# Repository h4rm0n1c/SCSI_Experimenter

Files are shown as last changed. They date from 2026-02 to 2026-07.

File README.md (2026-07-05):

# SCSI Experimenter

A 33C93A/WD33C93-based SCSI experimenter board for microcontroller projects, with a complete software architecture for running it from a Raspberry Pi Pico W or Pico 2 W.

## What it is

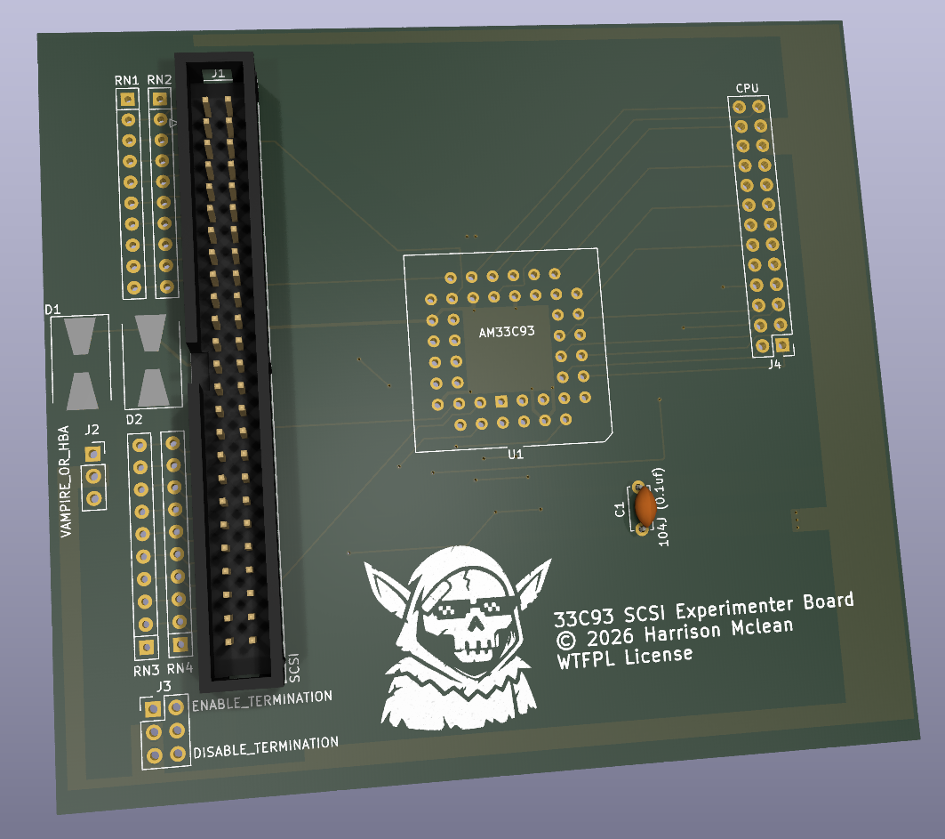
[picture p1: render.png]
SCSI Experimenter board render


This repo contains:

- **KiCad hardware design** — a breakout board built around the AM33C93A/WD33C93A SCSI bus interface controller, with a 26-pin CPU header and 50-pin SCSI-1 connector, passive 220/330Ω termination, and TERMPWR direction switch (HBA/vampire modes).
- **Complete software architecture** — verified PIO firmware design for initiator and target modes, documented at `ARCHITECTURE.md` (1184 lines).
- **Verification tools** — cycle-accurate PIO timing simulation, real `pioasm` compilation checks, and KiCad netlist extraction.
- **Datasheets** — AM33C93A, WD33C93A/B, RP2040, RP2350, and SCSI-1 spec, plus extracted text layers.

## Repository structure

```
├── ARCHITECTURE.md          — Complete software architecture reference
├── scsi/                    — KiCad PCB design files
│   ├── scsi.kicad_sch       — Schematic (S-expression)
│   ├── scsi.kicad_pcb       — PCB layout
│   └── scsi.kicad_pro       — Project metadata
├── h4rm0n1c.kicad_sym       — AM33C93A/AM33C93A KiCad symbol
├── render.png               — Board render
├── docs/                    — Datasheets and references
│   ├── AM33C93A.pdf         — AMD datasheet (49 pages)
│   ├── WD33C93A.pdf         — WD variant datasheet
│   ├── WD33C93B.pdf         — Enhanced version datasheet
│   ├── WD33C93A-appnotes.pdf — Combined datasheet + app notes + errata
│   ├── SCSI-1-spec.pdf      — ANSI X3.131-1986
│   ├── RP2040-datasheet.pdf — RP2040 microcontroller
│   ├── RP2350-datasheet.pdf — RP2350 microcontroller
│   ├── PicoW-pinout-diagram.pdf
│   ├── Pico2W-pinout-diagram.pdf
│   └── PICO_GPIO_CHEATSHEET.md — Verified GPIO reference
├── docs-extracted/          — pdftotext of searchable datasheets
│   ├── WD33C93A-appnotes.txt
│   └── WD33C93B.txt
└── tools/                   — Verification tools
    ├── check_pio_timing.py  — Stage 1: timing simulator
    ├── assemble_pio.py      — Stage 2: pioasm compilation + cross-check
    ├── extract_netlist.py   — KiCad PCB netlist dumper
    └── README.md            — Tool documentation
```

## Quick start

### 1. Hardware

The board has a 26-pin CPU header (J4) that connects directly to a Pico 2 W GPIOs — no level shifters required (RP2350 GPIOs are 5V tolerant). For RP2040/Pico W builds, a 74LVC8T245 is needed on the data bus.

See `ARCHITECTURE.md` §0 (§0 for the J4 pinout and §1 for the GPIO map.

### 2. Validation

From the repo root, verify the PIO design:

```bash
python3 tools/check_pio_timing.py   # timing simulation against datasheet specs
python3 tools/assemble_pio.py       # real pioasm compilation
```

Both should exit 0.

### 3. Reading the architecture

Start with `ARCHITECTURE.md`:

- **§0–1** — Board discovery and GPIO allocation
- **§2** — PIO state machine design (register engine + burst DMA)
- **§3** — Register access layer and C API
- **§4** — SCSI bus phase engine (initiator)
- **§5** — Interrupt vs polling vs DMA analysis
- **§6** — Clock generation
- **§7** — RP2040 vs RP2350 comparison
- **Appendices F–I** — Complete register reference, interrupt codes, command reference, target mode

## Architecture highlights

- **PIO-based bus interface** — two state machines in one PIO block (22 of 32 instruction slots), driving all 33C93A register accesses with hardware-bounded strobes. No CPU bit-banging.
- **Burst DMA** — DRQ/DACK-paced PIO engine + DMA channel for data phases, zero CPU per byte, ~2.5 MB/s throughput.
- **SM clock 24 MHz** — derived from 120 MHz sysclk, chosen so all timing minima land on integer cycle counts with margin.
- **Indirect addressing** — ALE is grounded on this board, so every register access is a two-cycle operation.
- **Dual board support** — same firmware binary runs on Pico W and Pico 2 W (Pico 2 W recommended for zero-glue wiring).

## Variant support

The architecture covers the full WD33C93 family — original WD33C93, WD33C93A, WD33C93B, and AMD AM33C93A. All variant-specific features are flagged `[A+]` or `[B]` throughout the reference. The fitted chip on this board is the WD33C93B, which is used as the primary reference.

## Target mode

The 33C93A supports both initiator and target SCSI roles. The architecture covers target mode in Appendix I, including Wait-for-Select-and-Receive (0Ch) as the recommended parked state, reselection handling, and the full set of target commands. The PIO layer is identical regardless of mode.

## License

WTFPL — see the schematic title block.

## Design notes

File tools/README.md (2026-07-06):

# Tools

Work products from the ARCHITECTURE.md design session (2026-07-05).
These regenerate/verify the evidence the architecture document is
built on. Run everything from the repo root.

## check_pio_timing.py — PIO program validator & timing simulator

```
python3 tools/check_pio_timing.py
```

Parses the `pioasm` code blocks **directly out of ARCHITECTURE.md** and:

1. **Encoding check** — enforces the `.side_set 3` (non-optional) field
   budget: side annotation on every instruction, side values ≤ 3 bits,
   delays ≤ `[3]`. This catches the class of bug found in review (the
   original draft used `.side_set 3 opt`, which only leaves 1 delay bit,
   with `[4]`/`[2]` delays that would not assemble).
2. **Cycle-accurate timing simulation** — replays each program at the
   24 MHz SM clock (120 MHz sys ÷ 5), measures every strobe's low width,
   inter-strobe recovery, and `in pins` sample age (including the
   2-sys_clk input-synchronizer latency, −16.7 ns), and asserts them
   against the WD33C93A app-notes limits (§9.1.3/9.1.4 indirect register
   access, §9.1.11/9.1.12 burst DMA).

Exit code 0 = all pass. **Re-run this after any edit to the PIO
listings, the SM divider, or the sys_clk choice in ARCHITECTURE.md** —
the spec table in the script is the single place the datasheet numbers
live.

## assemble_pio.py — stage-2: real pioasm compilation

```
python3 tools/assemble_pio.py
```

Runs **after** `check_pio_timing.py` as the second stage of a two-stage
validation. Stage 1 checks field budgets and simulates timing but only
*parses* the source; stage 2 feeds the exact same code blocks to the
real `pioasm` (prebuilt at
`/home/harri/pico/EBD_IPKVM/build/pioasm-install/pioasm/pioasm`, falls
back to `$PATH`, then to building from
`/home/harri/pico/pico-sdk/tools/pioasm`) and verifies its output:

- each `.program` compiles standalone (syntax, jump targets, delay
  limits — pioasm itself rejects the `.side_set 3 opt` + `[2+]` class
  of bug found in review, so this stage catches it mechanically);
- generated `sm_config_set_sideset(&c, 3, false, false)` matches the
  required 3-bit / mandatory / pins config for every program;
- instruction-array length, wrap(target,top), and the 32-slot budget;
- the `mov osr, ~null` idiom decodes to 0xA0EB
  (MOV | dest OSR | invert | src NULL), checked standalone and per
  occurrence in-program under the side/delay field mask;
- **cross-check against stage 1**: per-program instruction counts from
  `check_pio_timing.py`'s parser must match pioasm's — catches any
  extraction/regex divergence between the two tools;
- **pio_version must be 0** (RP2040/RP2350 compatible); a non-zero
  version means an RP2350-only instruction crept in and breaks the
  ARCHITECTURE.md both-boards guarantee → FAIL.

Exit 0 = all compiled and matched. Never modifies ARCHITECTURE.md —
it validates whatever the doc actually says.

## pio_sim.py — stage-3: behavioral simulation vs a mock 33C93A

```
python3 tools/pio_sim.py [-v]
```

Stage 1 proves the strobe timing, stage 2 proves the source assembles —
neither proves the programs implement the **protocol**. Stage 3
executes the programs cycle-by-cycle against a mock WD33C93A register
file and checks what the chip would actually *do*:

- **Executes real machine words.** A built-in assembler turns the
  ARCHITECTURE.md `pioasm` blocks into 16-bit PIO instructions, then a
  cycle-accurate SM model (OSR/ISR shifts, autopush/autopull, FIFO
  stalls, side-set-on-first-cycle, delay cycles, pindirs, the 2-sys_clk
  input-synchronizer age) decodes and runs the *words* — so a
  mis-encoded field is an execution failure. The assembled `sbic_bus`
  is cross-checked word-for-word against the pioasm 2.2.0 output
  captured in `../session/6e23006d-*` (golden reference embedded).
- **Mock chip enforces the datasheet at every pin edge**: indirect
  Address-register protocol with its auto-increment exceptions
  (Aux Status / Data 19h / Command 18h — app notes §6.2.2, B datasheet
  §3.1.2), strobe min/max widths and recovery (§9.1.3/9.1.4), read
  data driven only after tRLDV — a program that samples early gets
  garbage *and* a logged violation — data setup on writes, bus
  contention, DACK̅-vs-CS̅ exclusion (E024), MR̅ ≥ 1 µs, INTRQ
  set/clear semantics (§9.1.13), the 7 µs LCI rule, and DRQ̅/DACK̅
  burst handshaking.
- **Chip-variant-aware burst timing** (`chip_variant="A"|"B"` on
  `Bus`/`Sim`/`MockWD33C93A`, default A = worst case). A enforces
  §9.1.11/9.1.12: every read byte independently valid ≤ 50 ns from
  RE̅↓, strobes ≥ 80/50 ns, setup ≥ 25 ns, recovery ≥ 80 ns. B
  enforces §6.1.11/6.1.12: strobes ≥ 30 ns, setup ≥ 18 ns, and the
  *pipelined* read model — the mock only makes the first byte valid
  ≤ 50 ns from DACK̅↓ (tDLDV) and each later byte ≤ 80 ns from the
  *previous* RE̅↑ (tRHDV), so an SM that strobes faster than the
  pipeline delivers reads garbage and fails functionally.

Tests (any datasheet violation fails the test that produced it):

| Test | Proves |
|---|---|
| `golden-encoding` | assembler == session pioasm 2.2.0 words |
| `init-sequence` | **SM0 full init: MR̅ pulse → wait INTRQ → read SCSI Status (INTRQ clears) → write Own ID → read it back** |
| `aux-status` | A0=0 read returns Aux Status, Address reg untouched |
| `auto-increment` | CDB 03h–06h in 1+N cycles; Data 19h doesn't advance |
| `lci-7us-rule` | command <7 µs after status read ignored + LCI; ≥7 µs accepted (soft reset → interrupt 00h) |
| `burst-in` / `burst-out` | SM1 DRQ̅/DACK̅ bursts (A variant) move every byte in order, CS̅ high, completion INTRQ, DRQ̅ deasserts |
| `golden-burst-pipeline` | B variant: 12 bytes arrive intact under the pipelined validity model, and every prev-RE̅↑ → next-RE̅↓ gap ≥ 80 ns (the §2 claim that B data is stable before its strobe even falls) |
| `variant-probe` | Appendix E item 9 works: soft reset with EAF+RAF → SCSI Status 01h on both variants; CDB1 = microcode revision on a B, 0 on an A |
| `fifo-stall-hazard` | the §2 warning is real: a 5th un-drained SM0 read wedges `in pins` with RE̅ low, and the mock flags the tRE ≤ 10 µs violation |

The mock's checks are mutation-tested: shortening a strobe delay or
moving the read sample earlier makes the corresponding test fail.
Timing constants deliberately mirror `check_pio_timing.py`. Exit 0 =
all tests pass. Like the other stages it never modifies
ARCHITECTURE.md — it validates whatever the doc actually says.

**Validation flow after any PIO-related edit:**
```
python3 tools/check_pio_timing.py   # encoding budget + timing sim
python3 tools/assemble_pio.py       # real compiler + config verification
python3 tools/pio_sim.py            # behavioral sim vs mock 33C93A
```

## extract_netlist.py — KiCad PCB netlist dump

```
python3 tools/extract_netlist.py [repo/scsi/scsi.kicad_pcb]
```

Dumps pad → net for every footprint. The schematic has no net labels,
so this is how the J4 "CPU" header pinout, the grounded-ALE discovery,
the direct-to-header SCSI RST routing, and the J2/J3 termination/TERMPWR
analysis in ARCHITECTURE.md §0 were derived. U1 pads are annotated with
AM33C93A pin names (from `repo/h4rm0n1c.kicad_sym`, verified against the
AMD datasheet PLCC-44 connection diagram).

# ../docs-extracted/

`pdftotext` extractions of the datasheets that have text layers, kept
because the searchable text is what all register/timing citations in
ARCHITECTURE.md came from.

**OCR reliability status (verified 2026-07-05):** prose and register
bit descriptions extract fine, but **multi-column timing tables come
out with jumbled columns — do not trust extracted timing numbers.**
Every timing value used by ARCHITECTURE.md / check_pio_timing.py was
re-verified by reading the PDF pages as images: A app notes pp. 52–53
(indirect R/W), 60–62 (burst DMA, INTRQ); B datasheet pp. 47–49 (CLK,
MR̅, indirect R/W), 56–57 (burst DMA). The complete SCSI Status
interrupt-code tables and MCI decode (Appendix G) were likewise
verified against B datasheet pp. 21–24 — every code value, state
column, and meaning matched (one wording nuance fixed at 14h). One extraction-induced error was
found and fixed (A burst-read tRLDV is 50 ns, not 70), plus one real
finding (B burst reads are pipelined from DACK̅↓/previous RE̅↑). If you
pull new timing numbers from these .txt files, verify the page visually
first:

- `WD33C93A-appnotes.txt` — register map, indirect-addressing rules, all
  host-bus timing tables, errata index (E018/E022/E024/E040/E049…).
- `WD33C93B.txt` — command opcode table, B-variant differences.
- `SCSI-1-spec.txt` (ANSI X3.131-1986) — **kept local-only, not
  committed**: it is the full text of a paid ANSI standard. Regenerate
  with `pdftotext SCSI-1-spec.pdf docs-extracted/SCSI-1-spec.txt` from a
  locally obtained copy of the standard.

Not present: `AM33C93A.pdf` and `WD33C93A.pdf` are page scans with no
text layer (extraction yields nothing) — consult those PDFs visually;
the AMD PLCC-44 connection diagram is on datasheet page 1-5.

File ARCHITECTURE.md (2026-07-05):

# Pico ↔ AM33C93A SCSI Board — Software Architecture

Target: Raspberry Pi Pico W (RP2040) or Pico 2 W (RP2350) as the host
processor for the h4rm0n1c AM33C93A/WD33C93A experimenter board, SCSI-1
narrow initiator mode.

Sources: `repo/scsi/scsi.kicad_sch` + `scsi.kicad_pcb` (netlist verified
pad-by-pad), `repo/h4rm0n1c.kicad_sym`, AMD Am33C93A datasheet (Nov 1991,
pub #11853), WD33C93A datasheet + app notes (Nov 1990, incl. errata
E018/E022/E024/E049), WD33C93B datasheet, ANSI X3.131-1986,
`docs/PICO_GPIO_CHEATSHEET.md`, RP2040/RP2350 datasheets.

---

## 0. What the board actually is (netlist findings)

Extracted from `scsi.kicad_pcb` (authoritative — the schematic has no net
labels, everything is point-to-point wiring):

* **U1** — AM33C93A, PLCC-44. Pinout in the KiCad symbol matches the AMD
  datasheet connection diagram exactly.
* **J1** — 50-pin SCSI-1 connector. All odd pins + 20–24/28–30/34 GND,
  pin 25 open, pin 26 TERMPWR. SD0–SD7/SDP and the nine control lines go
  straight from U1's SCSI-side pins to J1 (open-drain 48 mA drivers on
  chip, no external transceivers — single-ended SCSI, as expected).
* **J4 "CPU"** — 26-pin (2×13) host header. **This is the Pico's world.**
  Full pinout below.
* **J3 "ENABLE_TERMINATION"** — connects the commons of RN1/RN3 (330 Ω)
  to GND and RN2/RN4 (220 Ω) to +5 V: classic SCSI-1 passive 220/330
  termination on all 18 signals, jumper-enabled.
* **J2 "VAMPIRE_OR_HBA"** — TERMPWR direction select through two SS33
  Schottkys: *HBA* position sources J1-26 TERMPWR from the board's +5 V
  (D1); *VAMPIRE* position back-feeds the board's +5 V rail *from* bus
  TERMPWR (D2).
* **ALE (U1 pin 27) is hard-wired to GND.** This is deliberate: per the
  WD33C93A datasheet §6.2.2, grounding ALE selects **indirect
  addressing** — there is no address bus, only A0. Every register access
  is a two-cycle operation (see §3).
* **SCSI RST (J1 pin 40) does not touch U1 at all** — the 33C93 family
  has **no RST pin**. The board routes RST straight to **J4 pin 7** so
  the host processor asserts and monitors bus reset itself.
* **DP (U1 pin 11 → J4 pin 3)** — host-bus data parity. On the PLCC part
  parity is *always generated* on DP during reads; *checking* of host
  parity is optional (Own ID bit EHP). Safe to leave unused.
* Test pins **1 (SI), 22 (SCLK), 36 (HALT)** are unconnected — correct
  per the AMD datasheet note ("test purposes only").

### J4 host header pinout (verified against PCB netlist)

| J4 pin | Signal | U1 pin | Dir (Pico view) | J4 pin | Signal | U1 pin | Dir |
|---|---|---|---|---|---|---|---|
| 1 | DRQ̅ | 9 | in | 2 | DACK̅ | 10 | out |
| 3 | DP | 11 | bidir (opt) | 4 | INTRQ | 12 | in (active **high**) |
| 5 | MR̅ | 40 | out | 6 | D1 | 14 | bidir |
| 7 | **SCSI RST̅** (J1-40) | — | open-drain bidir | 8 | D0 | 13 | bidir |
| 9 | CLK | 8 | out (8–16/20 MHz) | 10 | D3 | 16 | bidir |
| 11 | GND | | | 12 | D2 | 15 | bidir |
| 13 | GND | | | 14 | D6 | 19 | bidir |
| 15 | GND | | | 16 | D4 | 17 | bidir |
| 17 | GND | | | 18 | A0 | 21 | out |
| 19 | GND | | | 20 | D5 | 18 | bidir |
| 21 | +5V | | in/out (J2 mode!) | 22 | D7 | 20 | bidir |
| 23 | +5V | | | 24 | WE̅ | 25 | out |
| 25 | CS̅ | 24 | out | 26 | RE̅ | 26 | out |

16 logic signals + power. Fits a Pico with 10 GPIOs to spare.

> **Power note:** in HBA mode the Pico side must supply +5 V into J4-21/23
> (wire from Pico VBUS/VSYS). In VAMPIRE mode the SCSI bus supplies it —
> and could back-power the Pico via VSYS through a Schottky if you wire
> it that way. Pick one; don't fight USB power.
>
> **TERMPWR budget (HBA mode):** SCSI-1 §4.4.3 requires TERMPWR =
> **4.0–5.25 V** at up to 800 mA source capability. Path from USB:
> VBUS (4.75 V worst-case) → J4 → D1 SS33 (~0.35 V) ≈ **4.4 V** — in
> spec, but with little headroom, and both far-end terminators can draw
> ~160 mA static (18 lines × 5 V/550 Ω per end). A USB port + thin
> cable will sag. **Prefer an external 5 V supply into J4-21/23 for any
> setup with real termination load**; USB-only power is fine for a
> single short-cable bench target.

---

## 1. Hardware interface — GPIO allocation

### 5 V tolerance (the fork in the road)

* **RP2040 (Pico W): NOT 5 V tolerant.** Abs max = IOVDD + 0.5 V ≈ 3.8 V.
  Every signal the 33C93A can drive (D0–D7, DP, INTRQ, DRQ̅, SCSI RST̅)
  **must** be level-shifted 5 V → 3.3 V.
* **RP2350 (Pico 2 W): all GPIOs 5 V tolerant while powered**
  (VPIN_FT −0.5…5.5 V, RP2350 datasheet Table 1433). 5 V inputs connect
  **directly**.
* **3.3 V → 5 V direction needs no shifter on either board.** The AMD
  datasheet states "All inputs and outputs are TTL compatible", and the
  WD33C93A DC characteristics table confirms **V_IH = 2.0 V min for all
  inputs, with no CMOS-level exception for CLK**. RP2040 V_OH ≥ 2.62 V
  → ≥ 0.62 V worst-case margin. Use 8 mA drive + fast slew on CLK and
  the strobes. (The cheat sheet was over-conservative here; it has been
  corrected to match the datasheet DC spec.)

**RP2350/Pico 2 W: zero glue chips — wire J4 straight to the Pico 2.**

**RP2040/Pico W glue (required):**
* D0–D7: one **74LVC8T245** dual-supply transceiver (A-port 3.3 V,
  B-port 5 V). Wire **DIR = RE̅** (RE̅ low ⇒ B→A, chip drives Pico;
  RE̅ high ⇒ A→B). Add weak pull-ups on the A port so it doesn't float
  between read strobes while the Pico's pins are Hi-Z. OE̅ → GND (or CS̅).
* INTRQ, DRQ̅, RST̅ inputs: spare 74LVC245 / 74LVC2G34, or 10k/15k
  dividers (these edges are slow enough).
* Outputs (A0, CS̅, WE̅, RE̅, DACK̅, MR̅, CLK): direct, TTL-compatible.

### GPIO map (both boards — chosen for PIO side-set contiguity)

| GPIO | Signal | Direction | Why here |
|---|---|---|---|
| GP0–GP7 | D0–D7 | bidir | PIO `IN`/`OUT` pin base 0, contiguous |
| GP8 | A0 | out | 9th bit of the PIO `OUT` group (written with data) |
| GP9 | CS̅ | out | side-set group A base (register SM: CS̅/WE̅/RE̅) |
| GP10 | WE̅ | out | shared by both side-set groups |
| GP11 | RE̅ | out | |
| GP12 | DACK̅ | out | side-set group B base+2 (burst SM: WE̅/RE̅/DACK̅) |
| GP13 | CLK → 33C93 | out | PWM slice 6B — clock gen without PIO cost |
| GP14 | MR̅ | out | plain SIO GPIO (1 µs pulse, no timing pressure) |
| GP15 | INTRQ | in | GPIO IRQ, rising edge (active high) |
| GP16 | DRQ̅ | in | burst SM `WAIT`/`JMP PIN` |
| GP17 | DP | in (ignore) | leave EHP=0; parity is generated by chip anyway |
| GP18 | SCSI RST̅ | pseudo-open-drain | out-low ↔ input; GPIO IRQ falling = bus reset |
| GP19 | spare | — | LVC8T245 DIR override / logic-analyzer trigger |
| GP20, GP21 | UART1 TX/RX debug | — | GP21 doubles as `clk_gpout0` (alt CLK source) |
| GP22, GP26–28 | spare | — | GP26–28 = ADC (e.g. TERMPWR/divider monitor) |

Constraints honored: GP23–25 + GP29 reserved by CYW43439 on both W
boards; both side-set groups are contiguous (GP9–11 and GP10–12); data +
A0 form one contiguous 9-bit `OUT` group.

Init state: CS̅=WE̅=RE̅=DACK̅=MR̅=1, A0=0, RST̅ released (input).
**Errata E024:** DACK̅ must be held inactive whenever you use polled I/O
— the init state above satisfies it.

**DRQ̅ needs an external pull-up (~1 kΩ, hardware requirement).** The
WD pin description says DRQ̅ "can be an open drain output — a pullup
resistor is required when operating in DMA or Burst mode", and every
DMA timing table footnotes "external load on DRQ & DACK is assumed to
be 1 KΩ". The Pico's internal 50–80 kΩ pull is ~50× too weak: DRQ̅'s
rising (deasserting) edge would take ~1 µs, during which SM1 would
clock extra strobes into a chip that isn't ready. Fit ~1 kΩ from J4-1
to +5 V on the board side (RP2350 input tolerates it directly; on
RP2040 it sits on the 5 V side of the shifter). Firmware side: enable
`gpio_pull_up(16)` anyway (harmless belt-and-braces) and mask/ignore
DRQ̅ and INTRQ until `sbic_init()` completes — the reset-default
internal pull-*down* would otherwise read as DRQ̅ asserted while the
chip is still coming up.

**GP18 (SCSI RST̅) is *pseudo*-open-drain** — neither RP chip has true
open-drain pads. Assert = switch to output-low; release = switch back
to input and let the bus terminators restore the line (220/330
termination at both ends ≈ 3 V Thevenin, ~66 Ω — rise is fast, but a
long loaded cable adds RC). Rules: hold asserted ≥ 25 µs (SCSI-1 Reset
Hold Time, §4.7.12); after releasing, **wait ≥ 5 µs and read the pin
back high before any re-assertion or bus activity** so a still-rising
line is never glitched; never configure GP18 output-high even
momentarily (on RP2040 that fights a 5 V bus with a 3.3 V driver).

---

## 2. PIO state machine design

### Why PIO at all

The indirect-read timing table has a trap: **RE̅ pulse width is min
180 ns *and max 10 µs*** (WD33C93A §9.1.4). A CPU bit-banging RE̅ that
takes an interrupt mid-strobe violates the max and can corrupt the
access. PIO gives hard-bounded strobes regardless of CPU load, plus
FIFOs that DMA can feed. All host-side timing then derives from the PIO
clock divider, not from code path length.

Both SMs below live in **one PIO block** (they share pin mappings and
must be in the same block; only one runs at a time). Total = 22 of the
32 instruction slots.

### Side-set encoding budget (this constrains everything)

PIO instructions carry a single **5-bit delay/side-set field**, split by
the `.side_set` directive:

| Directive | side data | enable bit | delay bits | max `[n]` |
|---|---|---|---|---|
| `.side_set 3 opt` | 3 | 1 | 1 | `[1]` |
| **`.side_set 3`** (used here) | 3 | 0 | 2 | **`[3]`** |

We need 3 side-set pins per SM and delays up to 3, so side-set is
**non-optional** — which requires a `side` annotation on *every*
instruction (all listings below comply). Longer intervals than 4 cycles
are built by letting a strobe span **multiple instructions**: side-set
values persist until some later instruction changes them, so pulse
widths are not limited by the delay field.

### SM clock derivation

Inputs to the choice:

1. sys_clk = **120 MHz** (fixed by §6: integer-divides to the chip's
   15 MHz CLK, valid on both RP2040 and RP2350).
2. The SM divider must be a small exact integer (no fractional jitter
   in strobe widths).
3. PIO **input synchronizers are 2 sys_clk stages** (§3.5.6.3 RP2040):
   an `in pins` at SM cycle N reads the pin state from ~2/120 MHz =
   **16.7 ns earlier**. Every read-sample margin must absorb this.
4. All datasheet minimums should land on cycle counts reachable with
   `[3]` delays plus at most one extra `nop`, with real margin.

Take **divider = 5.0 → f_SM = 24 MHz, T = 41.67 ns** and check every
constraint (indirect mode, WD33C93A §9.1.3/9.1.4):

| Constraint | Spec | Cycles req'd | Achieved (below) | Margin |
|---|---|---|---|---|
| tCLWL/tCLRL (CS̅↓→strobe↓) | ≥ 0 | 0 | 0 (one side-set co-asserts) | — |
| tWE (WE̅ low) | ≥ 120 ns | ⌈120/41.67⌉ = 3 | 4 cyc = 166.7 ns | +46.7 ns |
| tDVWH (data setup→WE̅↑) | ≥ 70 ns | 2 | 5 cyc = 208.3 ns | +138 ns |
| tWHDI/tWHAI/tWHCH (holds) | ≥ 0 | 0 | pins held past strobe | — |
| tRE (RE̅ low) | ≥ 180 ns, ≤ 10 µs | 5 | 7 cyc = 291.7 ns | +111.7 ns / −9.7 µs |
| sample after RE̅↓ | ≥ tRLDV(180) + tsync(16.7) = 196.7 ns | 5 | cycle 6 = 250 ns → data age 233.3 ns | +36.6 ns |
| tWHWL/tRHRL (recovery) | ≥ 100 ns | 3 | 8 cyc = 333 ns | +233 ns |

(A ÷4 = 30 MHz SM also closes with one more nop per strobe; ÷5 is chosen
for margin. Anything ≥ ~30 MHz makes the cycle-6 sample land before
196.7 ns unless you add instructions — that, not the pulse width, is the
binding constraint on SM speed.)

### SM0 — register/PIO-mode bus cycle engine

One program does both directions. Each transaction is **one TX-FIFO
word**: `bit9 = R/W̅ (1 = read)`, `bit8 = A0`, `bits7:0 = data`
(don't-care for reads). Reads return one byte in the RX FIFO.

Required shift config (the program depends on it):
`sm_config_set_out_shift(right, autopull=OFF, —)` — OSR shifts right so
`out pins,9` peels bits 8:0 (A0+data) and `out x,1` then gets bit 9;
autopull must be off or the pull threshold would split the 10-bit word.
`sm_config_set_in_shift(left, autopush=ON, threshold=8)` — ISR shifts
left so the byte lands in bits [7:0] for byte-wide DMA/CPU reads.

```pioasm
.program sbic_bus
.side_set 3                ; {bit2=RE, bit1=WE, bit0=CS} base GP9, idle 0b111
; OUT pins: base GP0, count 9 (D0-7 + A0). IN pins: base GP0.

entry:
    pull block          side 0b111
    out pins, 9         side 0b111      ; latch data + A0 onto pin registers
    out x, 1            side 0b111      ; x = R/W flag
    jmp !x, wr          side 0b111
rd: mov osr, null       side 0b111
    out pindirs, 8      side 0b111      ; release D0-7 (A0 stays output)
    nop                 side 0b010 [3]  ; CS+RE fall at t=0; cycles 0-3
    nop                 side 0b010 [1]  ; cycles 4-5
    in  pins, 8         side 0b010      ; cycle 6: sample t=250ns, age 233ns >= 180 OK
    jmp entry           side 0b111 [1]  ; cycle 7: RE rises -> low 291.7ns in [180ns,10us]
wr: mov osr, ~null      side 0b111
    out pindirs, 8      side 0b111      ; D0-7 driven; data appears >= 1 cyc pre-strobe
    nop                 side 0b100 [3]  ; CS+WE low 4 cyc = 166.7ns >= tWE 120
    jmp entry           side 0b111 [1]  ; WE rises; data stays driven (hold >= 0)
```

Cycle accounting (convention: side-set asserts on an instruction's
*first* cycle; an instruction with delay d occupies 1+d cycles; a strobe
asserted by instruction i and released by instruction j is low for the
sum of the cycles of i..j−1):

* **Read:** RE̅ low = 4+2+1 = 7 cyc = 291.7 ns. Sample at cycle 6 =
  250 ns; minus 16.7 ns synchronizer age = 233.3 ns ≥ tRLDV 180 ✓.
* **Write:** WE̅ low = 4 cyc = 166.7 ns ≥ 120 ✓. Data valid from
  `out pindirs` (1 cyc before strobe) to WE̅↑ = 1+4 = 5 cyc = 208 ns ≥
  tDVWH 70 ✓ (worst case — if the previous transaction was also a write,
  the pins were driven far earlier). A0 valid 3 cyc = 125 ns before the
  strobe (tAVWL ≥ 0 ✓).
* **Recovery (both paths):** strobe↑ at `jmp`, next strobe↓ after
  `jmp[1]`(2) + entry(4) + mov/out(2) = 8 cyc = 333 ns ≥ 100 ✓.
* Totals: write transaction 12 cyc = 500 ns, read 13 cyc = 542 ns → one
  indirect register access (address cycle + data cycle) ≈ 1.0–1.05 µs.

14 instructions.

> **FIFO-stall hazard (the 10 µs RE̅ max):** with autopush, `in pins`
> *stalls with RE̅ held low* if the RX FIFO is full. Four un-drained
> reads is the FIFO depth — the register layer must consume each read's
> result before queueing a fifth (it is synchronous, so it does). Never
> fire-and-forget a batch of >4 read words at SM0.

*RP2040 note:* the LVC8T245 with DIR=RE̅ flips direction when RE̅
falls — prop delay ~5 ns, absorbed by the 250 ns sample point.

### SM1 — burst-DMA data-phase engine (DRQ̅/DACK̅)

Control register DMA mode = **Burst** (`DM = 001`): DRQ̅ stays asserted
while the chip's 12-byte FIFO can move data; the host answers with
DACK̅ + RE̅/WE̅ strobes, **CS̅ high**. Burst timing — **visually
verified against both datasheets' timing pages** (A app notes
§9.1.11/9.1.12 pp. 60–61; B datasheet §6.1.11/6.1.12 pp. 56–57):

* **A**: read strobe ≥ 80 ns, recovery ≥ 80 ns, data valid ≤ 50 ns from
  RE̅↓; write strobe ≥ 50 ns, setup ≥ 25 ns.
* **B** (fitted on the demo board) is faster and uses a *pipelined*
  read model: strobes ≥ 30 ns, recovery ≥ 30 ns, write setup ≥ 18 ns;
  read data for the **first** byte is valid ≤ 50 ns after DACK̅↓, and
  for each later byte ≤ 80 ns after the **previous RE̅↑** — RE̅ just
  advances the FIFO.

The SM below is sized to the A (the stricter chip) and satisfies the
B's pipelined model as a side effect: its previous-RE̅↑ → next-RE̅↓ gap
is ≥ 3 cyc = 125 ns ≥ 80, so byte N's data is stable before its strobe
even falls.

Constraint check at 24 MHz (A numbers = worst case):

| Constraint | Spec | Achieved |
|---|---|---|
| RE̅ low (read) | ≥ 80 ns | 4 cyc = 166.7 ns |
| sample after RE̅↓ | ≥ 50 + 16.7 = 66.7 ns | cycle 3 = 125 ns → age 108 ns |
| WE̅ low (write) | ≥ 50 ns | 2 cyc = 83.3 ns |
| data setup to WE̅↑ | ≥ 25 ns | 3 cyc = 125 ns |
| recovery | ≥ 80 ns | ≥ 3 cyc = 125 ns |

```pioasm
.program sbic_burst_in          ; SCSI DATA IN -> memory
.side_set 3                     ; {bit2=DACK, bit1=RE, bit0=WE} base GP10, idle 0b111
    wait 0 gpio 16      side 0b111     ; DRQ- asserted (2-stage sync, ~17ns late: harmless)
    nop                 side 0b001 [2] ; DACK+RE fall t=0; cycles 0-2
    in  pins, 8         side 0b001     ; cycle 3: sample t=125ns, age 108ns >= 70 OK
    jmp 0               side 0b111 [1] ; strobes rise: RE low 166.7ns >= 80 OK
```

```pioasm
.program sbic_burst_out         ; memory -> SCSI DATA OUT
.side_set 3
    wait 0 gpio 16      side 0b111
    out pins, 8         side 0b111     ; autopull(right,8); data 1 cyc pre-strobe
    nop                 side 0b010 [1] ; DACK+WE low 2 cyc = 83.3ns >= 50 OK
    jmp 0               side 0b111 [1] ; release; recovery >= 3 cyc = 125ns >= 80 OK
```

4 instructions each (8 slots total). Per byte: read ≥ 7 cyc = 292 ns,
write ≥ 6 cyc = 250 ns → ~3.4 MB/s engine ceiling; the chip's DRQ̅
handshake latency will dominate in practice. DMA byte-size accesses to
the TX FIFO are bus-replicated across the 32-bit word, and OSR
shift-right consumes bits [7:0] — so `DMA_SIZE_8` feeds `out pins,8`
correctly; on the read side ISR shift-left + autopush 8 puts the byte at
[7:0] where a `DMA_SIZE_8` read of the RX FIFO expects it. Keep the DMA
channel running for the whole transfer: pausing it can leave `in`
stalled with RE̅ low.

A **DMA channel** services each SM: RX FIFO → buffer (DREQ_PIOx_RXn) for
data in, buffer → TX FIFO (DREQ_PIOx_TXn) for data out, byte transfers,
IRQ_QUIET, count = transfer length. CPU involvement per data phase:
program Transfer Count, issue the chip command, start DMA, sleep until
INTRQ.

### SM0/SM1 handoff discipline

SM0 and SM1 overlap on WE̅/RE̅. A SM parked on a stalled `pull`
re-asserts its side-set (idle `0b111`) every stall cycle; if both SMs
ran at once, same-cycle writes to a shared pin resolve highest-SM-wins —
don't rely on it. Before starting a burst: drain SM0, then
`pio_sm_set_enabled(pio, sm_reg, false)` (CS̅ must be inactive during
DMA anyway per the datasheet), flip D0–7 pindirs for the transfer
direction (`pio_sm_set_consecutive_pindirs`), enable SM1 + DMA.
Reverse on completion.

### Explicit per-SM PINCTRL/shift configuration (not optional)

Each SM has its **own** OUT/IN/side-set pin mapping. SM1's `out pins,8`
/ `in pins,8` only hit D0–D7 if its OUT/IN base is explicitly set to
GP0 — it does *not* inherit anything from SM0, and an unset base
defaults to 0 only by accident of the reset value. Pin both down in
code:

```c
// SM0 — register engine
pio_sm_config c0 = sbic_bus_program_get_default_config(off_bus);
sm_config_set_out_pins    (&c0, 0, 9);        // D0-7 + A0
sm_config_set_in_pins     (&c0, 0);           // D0-7
sm_config_set_sideset_pins(&c0, 9);           // {CS,WE,RE} = GP9,10,11
sm_config_set_out_shift   (&c0, true,  false, 32); // shift RIGHT, autopull OFF
sm_config_set_in_shift    (&c0, false, true,  8);  // shift LEFT,  autopush 8
sm_config_set_clkdiv_int_frac(&c0, 5, 0);     // 120 MHz / 5 = 24 MHz

// SM1 — burst engine (either direction's program)
pio_sm_config c1 = sbic_burst_in_program_get_default_config(off_burst);
sm_config_set_out_pins    (&c1, 0, 8);        // D0-7 (burst_out)
sm_config_set_in_pins     (&c1, 0);           // D0-7 (burst_in)
sm_config_set_sideset_pins(&c1, 10);          // {WE,RE,DACK} = GP10,11,12
sm_config_set_out_shift   (&c1, true,  true,  8);  // autopull 8 (burst_out)
sm_config_set_in_shift    (&c1, false, true,  8);  // autopush 8 (burst_in)
sm_config_set_clkdiv_int_frac(&c1, 5, 0);
```

(The `wait 0 gpio 16` in the burst programs uses an *absolute* GPIO
index, so DRQ̅ needs no mapping — but GP0–12 must all be handed to the
PIO block with `pio_gpio_init()` and the side-set pins driven high
before either SM starts.)

### Optional SM2 — CLK generation

Two instructions (`set pins,1 [N] / set pins,0 [N]`) give any even
division of sysclk. **Don't spend an SM on this** — PWM does it free
(§6). Listed only as a fallback.

### Block/SM budget

| | RP2040 (Pico W) | RP2350 (Pico 2 W) |
|---|---|---|
| CYW43 WiFi driver | 1 SM + 1 DMA ch (default PIO1) | same |
| SCSI SM0+SM1 | PIO0 (2 of 4 SMs, ~26/32 slots) | PIO2 all to SCSI, PIO0/1 free |
| Headroom | 2 SMs in PIO0, 3 in PIO1 | 10 SMs elsewhere |

---

## 3. Register access layer

### Indirect addressing (ALE grounded — how this board works)

* Write the target register number with **A0 = 0** (loads Address reg).
* Access the register with **A0 = 1** (RE̅ or WE̅).
* The Address register **auto-increments** after each A0=1 access —
  *except* at Aux Status, **Data (19h)**, and Command (18h). So
  multi-byte register loads are 1 + N cycles, and the Data register can
  be streamed with repeated A0=1 accesses without re-addressing.
* **Auxiliary Status** is read directly with **A0 = 0** (single cycle,
  any time except during DMA).

### Register map (summary — full bit-level reference in Appendix F)

| Addr | R/W | Register |
|---|---|---|
| 00h | R/W | Own ID / CDB Size (SCSI ID 2:0, EAF, EHP, RAF[B], FS1:0 clock divisor) |
| 01h | R/W | Control (DM2:0 DMA mode, HHP, EDI, IDI, HA, HSP) |
| 02h | R/W | Timeout Period (select/reselect; value = Tper_ms × f_CLK_MHz / 80) |
| 03h–0Eh | R/W | CDB bytes 1–12 (a.k.a. Translate-Address geometry regs) |
| 0Fh | R/W | Target LUN (returns SCSI status byte after SAT command) |
| 10h | R/W | Command Phase (resume pointer for combination commands — Appendix H) |
| 11h | R/W | Synchronous Transfer (offset/period; 0 = async; FSS[B]) |
| 12h–14h | R/W | Transfer Count MSB/mid/LSB (24-bit) |
| 15h | R/W | Destination ID (+ TG1:0[B], DF[B], DPD, SCC) |
| 16h | R/W | Source ID (SIV/SI2:0, DSP, ES, ER) |
| 17h | R | SCSI Status (interrupt cause — reading clears INTRQ; Appendix G) |
| 18h | R/W | Command (bit7 = SBT single-byte transfer; opcodes in Appendix B) |
| 19h | R/W | Data (port into the 12-byte FIFO) |
| 1Ah | R/W | Queue Tag **[WD33C93B only]** |
| — (A0=0 read) | R | Auxiliary Status: INT LCI BSY CIP — FFE[B] PE DBR |

`[B]` = WD33C93B only (the demo board's fitted chip); absent/reserved-0
on WD33C93A/AM33C93A. See the Appendix F legend.

### C API (pico-sdk style)

```c
// ---- sbic_bus.c : PIO transport -------------------------------------
#define SBIC_XW(a0, d)   (((uint32_t)(a0) << 8) | (uint8_t)(d))        // write
#define SBIC_XR(a0)      ((1u << 9) | ((uint32_t)(a0) << 8))           // read

void     sbic_bus_init(PIO pio, uint sm_reg, uint sm_burst);
void     sbic_hw_reset(void);                 // MR- low >= 1 us, wait reset intr

// ---- register layer (indirect addressing under the hood) ------------
uint8_t  sbic_aux_status(void);               // 1 cycle: read A0=0
void     sbic_set_addr(uint8_t reg);          // 1 cycle: write A0=0
uint8_t  sbic_read_reg(uint8_t reg);          // set_addr + read A0=1
void     sbic_write_reg(uint8_t reg, uint8_t v);
void     sbic_write_regs(uint8_t first, const uint8_t *v, size_t n); // auto-inc
void     sbic_read_regs(uint8_t first, uint8_t *v, size_t n);        // auto-inc
static inline void sbic_command(uint8_t cmd)  { sbic_write_reg(SBIC_REG_CMD, cmd); }
static inline uint8_t sbic_scsi_status(void)  { return sbic_read_reg(SBIC_REG_SCSI_STATUS); }

// polled data-phase (DM=000): poll DBR in aux status per byte
int      sbic_pio_data_in (uint8_t *dst, size_t n, uint32_t timeout_us);
int      sbic_pio_data_out(const uint8_t *src, size_t n, uint32_t timeout_us);

// burst data-phase (DM=001): SM1 + DMA channel, returns immediately;
// completion signalled by INTRQ (chip) after transfer count exhausts
void     sbic_dma_data_in (uint8_t *dst, size_t n);
void     sbic_dma_data_out(const uint8_t *src, size_t n);
void     sbic_dma_abort(void);                // drain FIFO per datasheet 6.2.21

// 24-bit transfer count helper
void     sbic_set_xfer_count(uint32_t n);     // regs 12h..14h
uint32_t sbic_get_xfer_count(void);
```

Implementation notes:
* `sbic_write_reg` = push `SBIC_XW(0, reg)`, `SBIC_XW(1, v)` to SM0 TX.
* `sbic_read_reg` = push `SBIC_XW(0, reg)`, `SBIC_XR(1)`, pop RX.
* Because SM0's FIFO serializes transactions, the layer is naturally
  safe from strobe-timing races; guard it with a mutex if both cores use it.
* **7 µs rule:** the chip ignores a command written < 7 µs after the last
  SCSI Status read (sets LCI in aux status). Enforce with
  `busy_wait_us(7)` in `sbic_command()` after any status read, and check
  LCI afterwards.
* Never write Command while CIP or INT set; never issue a Level II
  command while BSY set (aux status gates all of this).

---

## 4. SCSI bus phase engine

### Division of labor

The 33C93A contains a microcontroller + SCSI sequencer. **It owns the
electrical phases**: arbitration (assert BSY/ID after bus-free
detection), selection with timeout, all REQ̅/ACK̅ byte handshakes, ATN
assertion, and — with the combination commands — entire command
executions. The Pico never touches BSY/SEL/REQ/ACK; they aren't even on
J4. Firmware works at the level of *"chip, do X" → INTRQ → read SCSI
Status → decide*.

### Two operating strategies

**A. High-level (recommended I/O path): Select-with-ATN-and-Transfer (08h)**

Setup: Own ID (done at init), Destination ID (15h), Target LUN (0Fh),
Sync Transfer = 0 (async), Transfer Count (12–14h), CDB into 03h–0Eh
via one auto-increment burst, Command Phase (10h) = 00, Control DM=001,
start the burst DMA engine, then `sbic_command(0x08)`.

The chip then executes ARBITRATION → SELECTION (with ATN) → MESSAGE OUT
(IDENTIFY built from Dest ID/LUN) → COMMAND (CDB from registers) → DATA
(via DRQ̅/DACK̅/DMA) → STATUS (latched into reg 0Fh) → MESSAGE IN
(Command Complete) and raises **one** interrupt (16h = success). Errors
/ disconnects suspend into the Command Phase register and are resumable
(IDI/EDI control bits govern disconnect interrupts). One IRQ per SCSI
command; this is the whole point of the part.

SAT-mode bug workarounds (E018 bug list, full text in the app notes):
* **P1** — a spurious DATA IN phase interrupt can follow the IDENTIFY
  message. Recovery: resume SAT with Command Phase register = 41h.
* **P2** — never issue **Assert-ATN (02h) during SAT's IDENTIFY or
  COMMAND phases**; the chip goes unpredictable. Queue the ATN request
  until the command phase completes (or run strategy B for that target).
* **P3 / E046** — on a target disconnect during DATA OUT, FIFO bytes
  are silently lost unless **IDI is set**, and the chip's internal
  transfer count can diverge from the host-side DMA count. Always set
  IDI when disconnects are enabled, and on any disconnect interrupt
  re-read Transfer Count (12h–14h) from the chip instead of trusting
  the DMA channel's remaining count.

**B. Low-level (bring-up, debug, unusual targets): phased engine**

Firmware state machine driven entirely by INTRQ:

```
IDLE ──select cmd (06h/07h)──► SELECTING
SELECTING ──intr── success codes ► CONNECTED   (timeout code ► IDLE)
CONNECTED: on every "REQ asserted" interrupt, SCSI Status low bits
           carry MCI (MSG,C/D,I/O) = the phase the TARGET now requests:
   000 DATA OUT   → set count, Transfer Info (20h), feed data
   001 DATA IN    → set count, Transfer Info, drain data
   010 COMMAND    → Transfer Info, send CDB bytes
   011 STATUS     → Transfer Info+SBT (80h|20h), read 1 byte
   110 MESSAGE OUT→ Transfer Info, send (e.g. IDENTIFY 80h)
   111 MESSAGE IN → Transfer Info+SBT, read byte, then Negate ACK (03h)
DISCONNECT interrupt ► IDLE (bus free)
```

Key rules encoded in the engine:
* The **target** dictates phases; the initiator only follows MCI. A
  "phase mismatch"-style interrupt (paused/aborted group, 2xh) simply
  means the target moved on — reload and issue the next Transfer Info.
* MESSAGE IN requires the explicit **Negate ACK (03h)** command after
  the byte is read (chip holds ACK so the initiator can inspect the
  message first). Related errata **E039**: ACK̅ may deassert before
  REQ̅ — treat REQ̅/ACK̅ ordering leniently when debugging message
  phases with a logic analyzer; it is a chip quirk, not a target fault.
* The MCI encoding above (000 = DATA OUT … 111 = MESSAGE IN, bit set =
  signal asserted) is taken from the datasheet §6.2.20 table. Errata
  **E067** ("logic orientation of SCSI phase bits") exists precisely
  because implementers got this inverted — its full text is not in the
  combined PDF, so **verify the orientation against a real target's
  COMMAND phase (MCI = 010) during bring-up** before trusting the
  decode table.
* **Assert ATN (02h)** before MESSAGE OUT if you need to send one
  mid-connection.
* SCSI Status code groups: `0x` reset, `1x` success, `2x`
  paused/aborted, `4x` terminated-with-error, `8x` bus service
  (reselection, unexpected phase). Low nibble = qualifier/MCI.

### Reset & init flow

```
1. Pulse MR- low >= 1 us; wait INTRQ; read SCSI Status (expect 00/01).
2. Write Own ID (00h) = FS bits | EAF | initiator SCSI ID (7).
3. sbic_command(RESET 00h); wait INTRQ (00h = plain, 01h = EAF acknowledged).
4. Write Control (01h): DM=000, no halts; Timeout Period (02h)
   (e.g. 250 ms @ 15 MHz -> 47); Sync Transfer (11h) = 0 (async);
   Source ID (16h): reselection disabled.
```

### SCSI RST̅ (GPIO18, firmware-owned)

* Assert: output-low ≥ 25 µs (SCSI-1 minimum), release to input.
  Afterwards re-run chip init (targets drop everything; the 33C93 does
  not see RST and must be told).
* Monitor: falling-edge GPIO IRQ → abort DMA, flush, mark bus dead,
  re-init. This is mandatory — the chip will never tell you.

---

## 5. Interrupt vs polling vs PIO — transfer-path analysis

| Mechanism | Latency | CPU cost | Timing risk | Use for |
|---|---|---|---|---|
| Poll aux status (DBR) per byte | ~1 µs/byte (2 reg cycles) | 100 % of a core | none (PIO strobes) | bring-up, tiny transfers, non-data phases |
| INTRQ GPIO IRQ | ~1–2 µs to handler | ~0 | must respect 7 µs cmd rule | **all command/phase events** |
| DRQ̅ polled by CPU | worse than DBR | high | E022 DRQ glitch errata (rev C/D) | never |
| **Burst DMA: DRQ̅-paced PIO SM + DMA ch** | 0 (hardware) | **0** | strobes hardware-bounded | **all DATA IN/OUT** |
| Single-byte DMA mode (DM=100) | 1 IRQ/byte equiv | high | — | never (burst supersedes) |

Recommended architecture:

* **Control plane = interrupt-driven.** INTRQ (GP15, rising) wakes a
  handler that reads SCSI Status once and feeds an event queue consumed
  by the phase engine (or completes the SAT command). Never issue chip
  commands from the ISR itself — the 7 µs rule and register-layer FIFO
  make a deferred worker (second core or main loop) cleaner. The Pico's
  free second core is a natural home for the whole SCSI stack, leaving
  core 0 for USB/WiFi/application.
* **Data plane = PIO SM1 + DMA in Burst mode.** Zero CPU per byte;
  completion = chip INTRQ (transfer count reached) + DMA count check.
  The 12-byte on-chip FIFO absorbs REQ/ACK vs host jitter.
* **Why not DACK-less polled data with DMA feeding SM0?** Possible
  (Data reg doesn't auto-increment away), but each byte must be gated on
  DBR, which DMA can't test — you'd throttle blind. Burst mode exists
  precisely for this; use it.
* **Errata to honor:** see the full matrix in **Appendix D**. The ones
  that shape this section: E024 (park DRQ̅/DACK̅ inactive in polled
  mode), E022 (ignore brief DRQ̅ deassertions — the `wait 0 gpio` +
  per-byte re-check pattern already handles it), E040 (after SAT, check
  PE bit even on success), E018-P3 (set IDI before SAT when disconnects
  + Data Out are possible, or FIFO bytes vanish silently).

Throughput reality check: SCSI-1 async tops out ≈ 1.5–2 MB/s on real
targets; the burst engine sustains ~2.5 MB/s+, chip ceiling 5 MB/s
(sync). The Pico is never the bottleneck.

---

## 6. Clock generation (33C93A CLK, pin 8 ← GP13)

Requirements: square wave, WD33C93A 8–16 MHz, WD33C93B/AMD-20 to
20 MHz, AMD-16 to 16 MHz. **Avoid 11 MHz** (divisor gap breaks bus-clear
timing). The Own ID FS field must match:

| f_CLK | FS1:0 | divisor | max transfer rate |
|---|---|---|---|
| 8–10 MHz | 00 | ÷2 | 4–5 MB/s |
| 12–15 MHz | 01 | ÷3 | 4–5 MB/s |
| 16 MHz (20 on -20/B parts) | 10 | ÷4 | 4–5 MB/s |

**Primary: PWM.** GP13 = PWM slice 6B. For an exact 50 % square wave use
integer division of sysclk:

* **Recommended: sys_clk = 120 MHz** (`set_sys_clock_khz(120000, true)`,
  fine on RP2040 and RP2350): PWM TOP=7, CC=4 → **15 MHz**, FS=01.
  Also makes the SM0/SM1 divider exact (÷5 → 24 MHz, 41.67 ns/cycle —
  the clock all of §2's delay counts are derived from; change either
  number and §2's constraint table must be re-run).
  120 MHz is USB-compatible on both chips — the SDK keeps PLL_USB at
  48 MHz independently of the sys PLL, and BOOTSEL mode runs on boot
  defaults regardless — but **"USB still enumerates at 120 MHz" belongs
  on the bring-up checklist**, verified once per board revision.
* 125 MHz default sysclk alternatives: ÷10 → 12.5 MHz (FS=01), ÷8 →
  15.625 MHz (out of the 12–15 band — don't).
* For a -20/B part chasing sync transfers: sys 160 MHz ÷ 8 = 20 MHz, FS=10.

Set 8 mA drive + `GPIO_SLEW_RATE_FAST` on GP13; keep the trace short.
On RP2040 builds the HCT/LVC output buffer squares it up anyway.

**Alternatives:**
* `clk_gpout0` on **GP21**: hardware clock output with its own divider,
  glitch-free, zero peripheral cost — but pin-fixed (GP21) and
  fractional division adds jitter, so use integer only.
* PIO 2-instruction toggler: works, wastes an SM.
* Canned oscillator on the board: only if you want the Pico removable;
  the board has no footprint for one, so PWM it is.
* Timeout register ties to this: `TPR = ceil(Tper_ms × f_MHz / 80)`
  → 250 ms @ 15 MHz = 47 (0x2F).

---

## 7. RP2040 (Pico W) vs RP2350 (Pico 2 W)

| Aspect | Pico W (RP2040) | Pico 2 W (RP2350) | Firmware impact |
|---|---|---|---|
| 5 V tolerance | None — shift all chip-driven lines | All GPIOs FT (powered) | **BOM: 2–3 ICs vs 0.** Same firmware; shifters are transparent. |
| PIO | 2 blocks / 8 SMs, CYW43 takes one | 3 blocks / 12 SMs | RP2350: park SCSI on PIO2, never contend with WiFi. Same programs (32-slot memory identical). |
| Sysclk default | 125 MHz | 150 MHz | Use `set_sys_clock_khz(120000)` on both → identical PWM/PIO divider math. (150 MHz ÷ 10 = 15 MHz also works if you stay stock on Pico 2.) |
| CPU | 2× M0+ | 2× M33 (or Hazard3) | Faster IRQ entry & phase engine; irrelevant to data plane (DMA does it). |
| SRAM | 264 KB | 520 KB | Bigger disk-block caches / more in-flight buffers. |
| Unpowered failsafe | — | FT pins only 3.3 V-safe unpowered | Power sequencing: don't leave the 5 V board driving a dead Pico 2 for long; shared power rail (J4 +5 V → VSYS via Schottky) sidesteps it. |
| Security/OTP | — | OTP, signed boot | Irrelevant here. |

**Recommendation: build on Pico 2 W.** Direct wiring (16 jumper wires),
a whole PIO block to itself, and headroom for a WiFi SCSI-over-TCP
bridge later. Keep the RP2040 build as a compile-time board variant —
nothing in the firmware architecture changes, only `#define`s for
shifter DIR handling (GP19) and clock setup.

---

## Appendix A — firmware module layout

```
src/
  sbic_bus.pio        SM0 register engine + SM1 burst in/out
  sbic_bus.c/.h       PIO/DMA transport, GPIO init, MR/RST control
  sbic_regs.h         register addresses, bit masks, command opcodes
  sbic.c/.h           chip driver: init/reset, command issue, IRQ handler,
                      aux/SCSI status decode, 7us guard, errata workarounds
  scsi_phase.c/.h     strategy B phase engine (Transfer Info per phase)
  scsi_sat.c/.h       strategy A: Select-w/ATN-and-Transfer wrapper
  scsi_initiator.c/.h public API: scsi_execute(cdb, dir, buf, len, &status)
  scsi_cmds.c/.h      INQUIRY / TEST UNIT READY / READ CAPACITY /
                      READ(6/10) / WRITE(6/10) / REQUEST SENSE builders
  main.c              core1: SCSI stack; core0: CLI/USB-MSC/WiFi bridge
```

## Appendix B — complete command reference

Command register (18h): bit 7 = **SBT** (single-byte transfer: disables
the Transfer Count for info-transfer commands, exactly one byte moves;
also lets Wait-for-Select-and-Receive accept a LUNTAR Identify),
bits 6:0 = opcode.

Rules: **Level I** commands (except Reset/Abort) complete without an
interrupt and may be issued while a Level II command runs. **Level II**
commands always end in an interrupt; issuing one while another Level II
runs (BSY set) is undefined; issuing any command with CIP or INT set is
ignored (LCI) or invalid. A Level II command issued in the wrong
chip state gives an "invalid command" interrupt (40h); a Level I command
in the wrong state is silently ignored. States: **D** disconnected,
**T** connected-as-target, **I** connected-as-initiator.

### Level I

| Op | Command | Valid | What it does |
|---|---|---|---|
| 00 | Reset | D,T,I | Soft reset: applies Own ID (ID, divisor, EAF/EHP/RAF), clears 01h–16h, ends with interrupt 00h (01h if EAF) |
| 01 | Abort | D,T | D: halt selection/reselection attempt (before arbitration won → 22h; after, de-assert IDs, target may still answer within 200 µs). T: halt Send/Receive — for Sends stop servicing DRQ immediately, for Receives KEEP servicing until the interrupt; count left in 12h–14h |
| 02 | Assert ATN | I | Announce pending message-out. Auto-negated before last Transfer Info byte / after SAT Identify / at bus free. **Never during SAT IDENTIFY/COMMAND phases (E018-P2)** |
| 03 | Negate ACK | I | Release ACK̅ held after Message-In pause, parity halt, advanced reselection, save-data-pointer, queue-tag mismatch[B], status parity error. Assert ATN *first* if replying MESSAGE REJECT / MESSAGE PARITY ERROR / INITIATOR DETECTED ERROR |
| 04 | Disconnect | T,I | Immediate release of all bus signals → D. Target: normal end-of-op disconnect. Initiator: bail-out (e.g. after timeout). Transfer Count NOT trustworthy afterwards |
| 0F | Set IDI | D,T,I | Set the Control IDI bit while a Level II command is running (register file is otherwise locked) — enables overlapped-I/O disconnect interrupts mid-command |

### Level II — simple

| Op | Command | Valid | What it does |
|---|---|---|---|
| 05 | Reselect | D | Arbitrate + reselect initiator in Destination ID (I/O̅ asserted) → connected-as-**target**. Timeout per 02h |
| 06 | Select-with-ATN | D | Arbitrate + select target in Destination ID, ATN̅ asserted before SEL̅ release → I. Timeout 42h / abort 22h; selection/reselection *of us* during arbitration → 8xh |
| 07 | Select-without-ATN | D | Same, no ATN̅ |
| 10–13 | Receive Command / Data / Message-Out / Unspecified-Info-Out | T | Target-role in-phases (I/O̅=0). Phase lines set from opcode: MSG,C/D = 10:(0,1) 11:(0,0) 12:(1,1) 13:(1,0). Receive **Data** (11h) honors Sync Transfer + Control DM bits; others polled/async |
| 14–17 | Send Status / Data / Message-In / Unspecified-Info-In | T | Target-role out-phases (I/O̅=1). MSG,C/D = 14:(0,1) 15:(0,0) 16:(1,1) 17:(1,0). Send **Data** (15h) honors Sync Transfer + DM bits |
| 18 | Translate Address | D,T | LBA→CHS using 03h–0Eh geometry aliases; overflow → 45h. Spare-sector compensation via Head/Cylinder Number preload |
| 20 | Transfer Info | I | One information phase in the direction/type the target requests (MCI from last 8x/1x interrupt). Preload Transfer Count (or SBT); for Data phases set DM bits + Sync Transfer first. Non-message-in → 18h+MCI on next REQ̅; Message-In → pauses 20h with ACK̅ held |

### Level II — combination

| Op | Command | Valid | What it does |
|---|---|---|---|
| 08 | Select-with-ATN-and-Transfer | D,I(resume) | Full initiator SCSI op: arbitrate, select+ATN, IDENTIFY (built from LUN reg ⊕ 80h/C0h per ER; +tag msg[B] per TG bits), CDB from 03h–0Eh (6/10/12 by group; CDB-Size for unknown groups in advanced mode), Data phase per Transfer Count/DM/Sync, Status → LUN reg, Command-Complete → 16h interrupt (EDI delays to disconnect). Resume by rewriting Command Phase + reissuing (Appendix H) |
| 09 | Select-without-ATN-and-Transfer | D,I(resume) | Same without ATN/IDENTIFY (expects COMMAND right after selection) |
| 0A | Reselect-and-Receive-Data | D,T(resume) | Target-role: reselect initiator, send IDENTIFY (+tag[B]), Receive Data-Out, then interrupt — or chain per EDI/SCC to 0Dh (SCC=0) / 0Eh (SCC=1) |
| 0B | Reselect-and-Send-Data | D,T(resume) | Same with Data-In to the initiator |
| 0C | Wait-for-Select-and-Receive | D,T(resume) | Idle until selected; auto-receive IDENTIFY (→ LUN reg; tag[B] → 15h/1Ah) and CDB (→ 03h–0Eh; group from byte 1, unknown group pauses 87h/phase 31h in advanced mode). EDI=1: auto-chain to Send-Disconnect-Message on read-class opcodes |
| 0D | Send-Status-and-Command-Complete | T | Sends status = CDB11, then Command-Complete (00h) or Linked-C-C (0Ah/0Bh per CDB12 bits 0–1); links chain to 0Ch's command fetch unless DF set |
| 0E | Send-Disconnect-Message | T | Sends Disconnect (04h) — preceded by Save-Data-Pointer (02h) if IDI=1 — then releases BSY̅ → D |

Removed vs the original WD33C93: Transfer Pad and initiator-mode Abort
(do not use on A/B). Tag-message behavior throughout (TG bits, Queue
Tag register, phase values 21/22/70/71) is **[B] only**.

## Appendix C — host-bus timing minima used by the PIO programs

All values below were **visually verified against the PDF timing pages**
(A app notes pp. 52–53, 60–62; B datasheet pp. 47–49, 56–57) because the
text-layer extraction of these tables was unreliable.

Indirect write (identical A and B): tWE ≥ 120 ns, data setup ≥ 70 ns,
hold 0, recovery ≥ 100 ns (B adds tWHCH min −5 ns — CS̅ may rise just
before WE̅; we co-deassert, unaffected).
Indirect read: tRE ≥ 180 ns **and ≤ 10 µs**; data valid ≤ 180 ns (A) /
≤ 162 ns (B) from RE̅↓; data held 5–40 ns after RE̅↑; recovery ≥ 100 ns.
Burst DMA (A, governing worst case): write strobe ≥ 50 ns, setup ≥ 25 ns,
read strobe ≥ 80 ns, read data valid ≤ 50 ns from RE̅↓, recovery ≥ 80 ns,
DACK̅↔strobe skew ≥ 0. (B: strobes ≥ 30 ns and a pipelined read model —
see §2.) MR̅ ≥ 1 µs. INTRQ: rises ≥ 0 before RE̅↓ of the status read,
falls ≤ 100 ns after RE̅↑, stays low ≥ 100 ns before re-asserting.
CLK (E018 revision; B §6.1.1 identical): period 50–125 ns →
**8–20 MHz**, high/low ≥ 20 ns.

## Appendix D — errata matrix (WD app notes index #071-A + included texts)

The combined PDF contains the **index** of all app notes but full text
for only some. "In PDF" = full write-up available in
`docs/WD33C93A-appnotes.pdf` / `docs-extracted/WD33C93A-appnotes.txt`.

| # | Subject | Impact on this design | Handling |
|---|---|---|---|
| E018 (in PDF) | WD33C93A bug list P1–P7 + 20 MHz clock spec | P1 spurious DATA IN after IDENTIFY (SAT); P2 Assert-ATN during SAT IDENTIFY/COMMAND = undefined behavior; P3 FIFO loss on DATA OUT disconnect; P5 false bus-free on ≥200 ns BSY/SEL glitches | §4 strategy-A workarounds; keep termination clean (P5); P4/P6/P7 are target-mode/WD-bus only — N/A |
| E022 | DRQ̅ may glitch-deassert (rev C/D) | burst engine pacing | per-byte `wait 0 gpio` re-check absorbs it |
| E024 | DRQ̅/DACK̅ must be false in polled I/O | init/idle state | DACK̅ idles high (§1) |
| E039 | ACK̅ may deassert before REQ̅ | initiator handshake appearance on the wire | tolerance note in §4; no firmware action — chip-internal handshake |
| E040 | Parity error masked by other interrupts in SAT | error detection | check PE (aux status) after every SAT completion, even 16h success |
| E043 | Aux Status register usage notes | DBR polling edge cases | **full text not in PDF — obtain before relying on DBR corner cases**; polled path is bring-up-only here, burst DMA path unaffected |
| E044 | How to abort Wait-for-Select-and-Transfer | abort paths | initiator-only design never issues WFS; if reselection is later enabled, obtain this note first |
| E046 | Unexpected disconnect ⇒ internal vs external transfer counts diverge | SAT + DMA byte accounting | on any disconnect interrupt, re-read Transfer Count 12h–14h from chip; never trust DMA remaining-count (§4) |
| E049 | ALE maximum timing | none | **N/A — ALE is grounded on this board** (indirect addressing) |
| E066 | Command/interrupt matrix | firmware correctness reference | obtain; use as the truth table for the §4 event handler |
| E067 | SCSI Status phase-bit orientation | MCI decode in strategy B | verify decode against a live COMMAND phase at bring-up (§4) |
| E025, E031, E033, E042, E045, E047, E048, E050, E062, E065, E070, E071 | conversion guides, noise paper, transfer-mode descriptions, reserved-bit rule | background | E070: always write reserved register bits as 0 (already required by datasheet note) |

## Appendix E — bring-up checklist

1. USB enumerates with `set_sys_clock_khz(120000, true)` (PLL_USB stays
   at 48 MHz; BOOTSEL uses boot defaults — but verify once per board).
2. CLK at U1 pin 8: 15 MHz, ≥ 20 ns high and low (scope).
3. `tools/check_pio_timing.py` passes after any PIO/clock edit.
4. MR̅ reset → INTRQ fires, SCSI Status reads 00h/01h.
5. Register file walk: write/read-back CDB regs 03h–0Eh via
   auto-increment, confirm Address register behavior (Data/Command/Aux
   excluded from auto-increment).
6. DRQ̅ external ~1 kΩ pull-up fitted; DRQ̅ reads high (deasserted)
   after init, before any transfer command.
7. MCI orientation check against a real target: SELECT then confirm the
   first bus-service interrupt decodes as COMMAND phase (MCI = 010) —
   validates the E067 concern.
8. TERMPWR ≥ 4.0 V at J1-26 under full termination load (both
   terminator packs jumpered).
9. Variant probe: soft-reset with EAF=1 — SCSI Status 01h confirms
   A/B-class silicon; with RAF=1[B], CDB1 returns the microcode
   revision (B only).

---

# Complete Programming Reference (WD33C93 / 93A / 93B)

Everything firmware-facing, consolidated from the WD33C93B datasheet
(§3.1.1–3.1.23, §4), the WD33C93A app notes, and the E062 family-
difference notes — so nobody has to cross-reference four PDFs.

**Variant legend** — the PLCC-44 socket takes any of the three:
* *(no flag)* — WD33C93, 93A, AM33C93A, 93B all implement it.
* **[A+]** — added on WD33C93A/AM33C93A; absent on plain WD33C93.
* **[B]** — WD33C93B only (**the chip fitted on the demo board**);
  reserved/zero on A. Firmware that must run on both chips: write
  [B] bits as 0 and don't read [B] registers on an A.

## Appendix F — register reference (bit-level)

Access convention (this board, ALE grounded → indirect addressing):
write register number with A0=0, access with A0=1; auto-increment
except at Data (19h) and Command (18h); Aux Status = read with A0=0.

### Aux Status (read A0=0; direct-mode address 1Fh) — read-only

| Bit | Name | Meaning |
|---|---|---|
| 0 | DBR | Data register ready: set when FIFO can give (in) / take (out) a byte in polled I/O; cleared by the Data access |
| 1 | PE | Parity error seen on a received byte (SCSI always checked; host side only if EHP). Set regardless of HSP/HHP. Cleared by next command |
| 2 | FFE **[B]** | FIFO full/empty: with DBR set, host may write 11 / read 12 bytes without re-polling DBR (two exceptions: first fill after Transfer Info/Send allows 12; never write the *last* message-out byte until the chip re-requests it) |
| 3 | 0 | reserved |
| 4 | CIP | Command being interpreted — Command register unavailable |
| 5 | BSY | Level II command executing — only Command (if CIP=0), Data, Aux Status accessible |
| 6 | LCI | Last command ignored (issued too close to a pending interrupt — the 7 µs rule) |
| 7 | INT | Mirrors INTRQ pin; read SCSI Status to clear |

### 00h — Own ID / CDB Size (R/W)

Sampled **only by the Reset command** (mode 1). In advanced mode
(mode 2) bits 3:0 = CDB length for unknown command groups.

| Bit | Name | Meaning |
|---|---|---|
| 2:0 | ID2:0 | Own SCSI bus ID for arbitration/selection |
| 3 | EAF | Enable advanced features (§4.3.1 [B numbering]: unexpected-reselection Identify fetch, unknown-CDB-group handling, DPD direction check). Reset interrupt becomes 01h |
| 4 | EHP | Enable host-bus parity *checking* (generation on DP is always on) |
| 5 | RAF **[B]** | Really-advanced features: microcode rev → CDB1 at reset, immediate halts, protocol-error interrupt 25h, unexpected-bus-free 41h/85h. **Incompatible with A firmware expectations** |
| 7:6 | FS1:0 | Input-clock divisor: 00=÷2 (8–10 MHz), 01=÷3 (12–15 MHz), 10=÷4 (16 MHz A / 16–20 MHz B & AMD-20), 11=undefined. Never use 10–12 MHz |

### 01h — Control (R/W)

| Bit | Name | Meaning |
|---|---|---|
| 0 | HSP | Halt on SCSI parity error (Receive/Transfer Info). Initiator: ACK̅ left asserted to freeze the target. Sync transfers check on 4096-byte boundaries (every byte if RAF[B] immediate halt) |
| 1 | HA | Target mode: halt Send/Receive when initiator asserts ATN̅ (checked at start / 4096-byte boundaries / end; continuous with RAF[B]) |
| 2 | IDI | Intermediate disconnect interrupt (initiator, SAT): proper target disconnect → 85h + suspend, resumable. Target combo commands: execution-option select. **Required set when disconnects enabled + Data-Out expected (E018-P3)** |
| 3 | EDI | Ending disconnect interrupt: delay SAT's 16h until the target disconnects (replaces 85h); target side: enables command chaining (0A/0B→0D/0E, 0C auto-disconnect on reads) |
| 4 | HHP | Halt on host parity error (Send/Transfer out). ACK̅ *not* held. Needs EHP=1 |
| 7:5 | DM2:0 | 000 polled I/O · 001 Burst (demand DMA — **this design's data plane**) · 010 WD-bus/DBA (bus-master into external RAM; RE̅/WE̅/DACK̅ reverse direction — unused here) · 100 single-byte DMA |

### 02h — Timeout Period (R/W)

`value = ceil(Tper_ms × Ficlk_MHz / 80)` (undivided CLK); 0 disables.
Governs Select/Reselect BSY̅-response wait. 15 MHz, 250 ms → 47.

### 03h–0Eh — CDB 1–12 / Translate-Address aliases (R/W)

One register file, three uses:

| Addr | As CDB | As Translate Address | Other |
|---|---|---|---|
| 03h | CDB1 | Total Sectors (per track) | microcode rev after reset [B, RAF] |
| 04h | CDB2 | Total Heads | |
| 05h/06h | CDB3/4 | Total Cylinders MSB/LSB | |
| 07h–0Ah | CDB5–8 | Logical Address MSB…LSB (32-bit in) | |
| 0Bh | CDB9 | Sector Number (result) | |
| 0Ch | CDB10 | Head Number (result; preload spares/cylinder for compensation, else 0) | |
| 0Dh | CDB11 | Cylinder MSB (result) | status byte to send, for 0Dh command |
| 0Eh | CDB12 | Cylinder LSB (result) | link-control bits for 0Dh (bit0 linked, bit1 flag) |

### 0Fh — Target LUN (R/W)

| Bit | Name | Meaning |
|---|---|---|
| 2:0 | TL2:0 | LUN for IDENTIFY generation/check (SAT, RAT) |
| 6 | DOK | Disconnect-OK: WFSR: initiator allowed disconnects. SAT: with ER=1, respond to reselection but send IDENTIFY without disconnect privilege |
| 7 | TLV | Identify-valid flag (WFSR result; keep 0 when issuing SAT) |

Also receives: target's status byte (SAT), reselecting LUN/target-routine
number (advanced-mode unexpected reselection).

### 10h — Command Phase (R/W) — see Appendix H

Progress/resume pointer for combination commands. Read after abnormal
termination to locate the failure; write before reissuing to resume.

### 11h — Synchronous Transfer (R/W)

| Bit | Name | Meaning |
|---|---|---|
| 3:0 | OF3:0 | REQ/ACK offset 0–12. **0 = asynchronous** (this design's default). Values 13–15 undefined |
| 6:4 | TP2:0 | Min transfer period in internal-clock cycles: 000=8, 001=2, 010=3, 011=4, 100=5, 101=6, 110=7 (sync pulse widths in parentheses in datasheet table). Non-data phases always use 6 |
| 7 | FSS **[B]** | Fast SCSI: with ÷4 (16–20 MHz clock), doubles the internal transfer clock → up to 10 MB/s sync. No effect on async |

Internal cycle = divisor / (2 × Ficlk); with FSS[B] at ≥16 MHz:
2 / ((FSS+1) × Ficlk).

### 12h–14h — Transfer Count (R/W, 24-bit MSB first)

Preloaded before Send/Receive/Transfer Info (0 or SBT ⇒ single byte,
counter disabled). After success: 0. After halt/abort/phase change:
**bytes NOT transferred over SCSI, including bytes stranded in the
FIFO** — hence it can legitimately differ from the Pico DMA channel's
count (E046: always trust these registers, not the DMA remainder).

### 15h — Destination ID (R/W)

| Bit | Name | Meaning |
|---|---|---|
| 2:0 | DI2:0 | Bus ID to select/reselect |
| 4:3 | TG1:0 **[B]** | Tag message for SAT/WFSR/RAT: 00 none, 01 Simple (20h), 10 Head-of-queue (21h), 11 Ordered (22h) |
| 5 | DF **[B]** | Disable: DPD direction check + auto 0Dh→0Ch link on linked-command-complete |
| 6 | DPD [A+] | Expected SAT data-phase direction (0=out, 1=in); mismatch → unexpected-phase interrupt (advanced mode; disabled by DF[B]) |
| 7 | SCC [A+] | RAT chain select when EDI=1: 0 → Send-Status-and-Command-Complete, 1 → Send-Disconnect-Message |

### 16h — Source ID (R/W)

| Bit | Name | Meaning |
|---|---|---|
| 2:0 | SI2:0 | Bus ID of the device that (re)selected us (valid iff SIV) |
| 3 | SIV | Set when the (re)selector asserted its own ID bit |
| 5 | DSP | Disable parity check during selection/reselection response |
| 6 | ES | Enable response to **selection** (target-mode master switch) |
| 7 | ER | Enable response to **reselection** (initiator disconnect/reconnect support; also sets IDENTIFY bit 6) |

### 17h — SCSI Status (read-only) — see Appendix G

Cause of the last INTRQ; frozen until read; reading clears INTRQ.
Then wait ≥ 7 µs before writing Command (LCI rule).

### 18h — Command (R/W) — see Appendix B

### 19h — Data (R/W)

Port into the 12-byte FIFO, all phases and both DMA/processor paths.
Polled rules: only touch when DBR=1 (exception: advanced-mode
reselection Identify must be read out regardless); FFE[B] batch rules
in the Aux Status row above; during a Data phase only touch it if
DM=000 or you've quiesced the DMA interface (DACK̅ inactive). If a
command halts (abort etc.), **keep servicing the FIFO until the
interrupt arrives** or the chip stays wedged.

### 1Ah — Queue Tag (R/W) **[B only]**

Second byte of tag messages: sent by SAT/RAT after the tag code;
receives the incoming tag from WFSR/SAT-reselection. SAT compares the
reselection tag with the previous contents — mismatch → interrupt 26h
with ACK̅ held.

### Reset behavior

| Condition | Hard reset (MR̅) | Soft reset (cmd 00h) |
|---|---|---|
| Aux Status | cleared; INT set when done | DBR cleared; INT set when done |
| Own ID (00h) | **cleared** | interpreted (ID, divisor, EAF/EHP/RAF applied) |
| 01h–15h | **preserved** | cleared (01h–16h) |
| Source ID ES/ER/DSP | cleared (bits 0–3 preserved) | cleared (whole 16h) |
| SCSI Status | 00h | 00h (01h if EAF set) |
| FIFO/counters/offsets/state | cleared | cleared; SCSI signals released |
| Divisor | ÷2 | per FS1:0 |

WD's suggested SCSI-RST handling fits GP18 exactly: OR the incoming
bus-reset into MR̅ (or, as here, take the GPIO IRQ and pulse MR̅ in
firmware), then rebuild state from the preserved 01h–15h registers.

## Appendix G — SCSI Status (17h) interrupt code reference

Code = `GGGGQQQQ`: high nibble = group, low nibble = qualifier. Where
the qualifier is shown as `1MCI`, bit 3 is 1 and bits 2:0 are the
**MCI** phase code of the *requested* phase (verify orientation at
bring-up — E067):

| MCI | Phase | MCI | Phase |
|---|---|---|---|
| 000 | DATA OUT | 100 | unspec. info out |
| 001 | DATA IN | 101 | unspec. info in |
| 010 | COMMAND | 110 | MESSAGE OUT |
| 011 | STATUS | 111 | MESSAGE IN |

States: D disconnected, T target, I initiator. "→" = recommended
firmware action.

### 0xh — reset complete

| Code | State | Meaning → action |
|---|---|---|
| 00 | D,T,I | Hard reset or soft reset (EAF=0) done → program Own ID, issue Reset cmd (first time) or re-init |
| 01 | D,T,I | Soft reset done with EAF=1 → proceed to Control/Timeout/Source ID setup |

### 1xh — successful completion

| Code | State | Meaning → action |
|---|---|---|
| 10 | D | Reselect (05h) won → now T; proceed with IDENTIFY out |
| 11 | D | Select (06/07h) won → now I; await 8MCI phase request |
| 13 | T | Receive/Send/RAT/WFSR/0Dh/0Eh done, ATN̅ negated → next target phase (for WFSR: parse CDB in 03h–0Eh) |
| 14 | T | As 13 but **ATN̅ asserted** (and 0Eh not in this list — a completed disconnect can't see ATN) → issue Receive Message Out (12h) first |
| 15 | D,T | Translate Address done → read CHS results |
| 16 | I | SAT complete → read status from LUN reg (0Fh); check PE (E040) |
| 18+MCI | I | Transfer Info (non-msg-in) done; target now requests MCI → run the phase engine on MCI |

### 2xh — paused / aborted

| Code | State | Meaning → action |
|---|---|---|
| 20 | I | Transfer Info (Message In) paused, **ACK̅ held** → inspect byte; ATN+message-out to object, then Negate ACK (03h) |
| 21 | I | Save-Data-Pointer received during SAT → save host data pointer, resume SAT (phase 41h) |
| 22 | D | Select/Reselect/WFSR aborted (Abort cmd or selection abort) → idle |
| 23 | T | Receive/Send aborted, or WFSR got bad IDENTIFY (ATN̅ off) → Transfer Count = residue |
| 24 | T | As 23 but ATN̅ asserted → service message out |
| 25 | T | Transfer corrupted by REQ/ACK noise (protocol error) **[B, RAF]** → treat data as suspect, retry |
| 26 | I | Reselected by process with mismatched queue tag **[B]**, ACK̅ held; new tag now in 1Ah → context-switch or reject |
| 27 | I | Advanced-mode SAT: reselected by wrong target/LUN; ID in 16h, LUN in 0Fh, ACK̅ held → save state of current op, service the interloper (multi-threaded I/O) or reject |

### 4xh — terminated with error

| Code | State | Meaning → action |
|---|---|---|
| 40 | D,T,I | Invalid command for current state → firmware bug; log |
| 41 | T,I | Unexpected disconnect (bus went free) → now D; fail the op (with RAF[B] may also be a SEL glitch, E062) |
| 42 | D | Select/Reselect timeout (per 02h) → no such device |
| 43 | T,I | Parity error terminated a command (ATN̅ off); direction ⇒ SCSI vs host side → error recovery, count in 12h–14h |
| 44 | T | As 43 with ATN̅ asserted → service message out |
| 45 | D,T | Translate Address overflow (LBA beyond disk) → reject |
| 46 | I | Non-advanced SAT: reselected by wrong-ID target; still connected → sort it out manually (Transfer Info) or Disconnect |
| 47 | I | Status byte had parity error during SAT, ACK̅ held → ATN + INITIATOR DETECTED ERROR, or accept via Negate ACK |
| 4MCI (bit3=1) | I | **Unexpected phase** MCI requested (count ≠ 0 mid-Transfer-Info, or SAT protocol deviation) → the normal "target changed phase early" path: reload phase engine from MCI (check PE first on sync transfers) |

### 8xh — service required

| Code | State | Meaning → action |
|---|---|---|
| 80 | D | Reselected (normal mode) → now I; read 16h for reselector, resume that op |
| 81 | D | Reselected (advanced mode); IDENTIFY **in Data register**, ACK̅ held → read 19h, match to a suspended op, Negate ACK |
| 82 | D | Selected, no ATN̅ → now T; expect COMMAND out (Receive Command 10h) |
| 83 | D | Selected with ATN̅ → now T; Receive Message Out (12h) first |
| 84 | T | ATN̅ asserted mid-operation → Receive Message Out |
| 85 | T,I | Target disconnected (T: after our 0Eh; I: IDI-enabled SAT suspension, Command Phase = 43h) → park op, bus is free |
| 87 | T | WFSR paused: unknown CDB group (advanced); opcode in CDB1, phase = 31h → write total CDB length into 00h bits 3:0, reissue 0Ch to resume. Only Resume-WFSR/Abort/Disconnect/Reset accepted while paused |
| 8MCI (bit3=1) | I | REQ̅ asserted while initiator-idle: target requests phase MCI → issue Transfer Info (the phase engine's main event) |

## Appendix H — Command Phase register (10h) values

The heart of combination-command recovery: on any abnormal SAT/RAT/WFSR
termination, read 10h to see how far it got; to resume, write a valid
resume value (right column ✓) and reissue the same command opcode.

### Select-and-Transfer (08/09h)

| Value | Got this far | Resume? |
|---|---|---|
| 00 | nothing — still disconnected | reissue from scratch |
| 10 | target selected | ✓ |
| 20 | IDENTIFY sent | ✓ (implied Negate ACK) |
| 21/22 **[B]** | tag code / queue tag sent | ✓ 22 (implied Negate ACK) |
| 30 | COMMAND phase begun, 0 bytes | ✓ |
| 3x | x CDB bytes transferred | — |
| 41 | Save-Data-Pointer received | ✓ (implied Negate ACK; also the E018-P1 workaround resume point) |
| 42 | Disconnect message received, bus not yet free | ✓ (complete the disconnect) |
| 43 | target disconnected (bus free) | — (wait for reselection or abort) |
| 44 | reselected by matching target | ✓ (expects IDENTIFY in) |
| 45 | IDENTIFY (+tag[B]) verified after reselection | ✓ (more data; implied Negate ACK) |
| 46 | Data phase complete (count = 0) | ✓ (expects Status; **no** implied Negate ACK) |
| 47 | Status phase begun | — |
| 50 | status byte in 0Fh | ✓ (complete Command-Complete msg) |
| 60 | Command-Complete received | ✓ |
| 70/71 **[B]** | IDENTIFY matched, tag expected / Simple-Queue-Tag received | ✓ 70 (implied Negate ACK) |

### Reselect-and-Transfer (0A/0Bh)

00 idle · 10 initiator reselected (resume ✓ → IDENTIFY out) ·
20 IDENTIFY sent (resume ✓ → data phase; count 0 ⇒ skip to chain) ·
46 data transfer complete.

### Wait-for-Select-and-Receive (0Ch)

00 idle · 10 selected (resume ✓: message-out if ATN else command) ·
20 got Identify byte → 0Fh (resume ✓: validate) · 21 got tag code
(resume ✓)[B] · 22 got queue tag[B] · 30 ready for COMMAND phase
(resume ✓) · 31 1 CDB byte in — unknown-group pause point (resume ✓
after loading CDB size, see 87h) · 3x x CDB bytes in.
Paused interrupts at phase 20/21 = invalid message byte; Identify
parity error leaves phase = 10 so a plain reissue retries cleanly.

### Send-Status-and-Command-Complete (0Dh)

00 nothing (ATN̅ was up) · 50 status sent (resume ✓) · 60
Command-Complete sent · 61 Linked-Command-Complete sent.

### Send-Disconnect-Message (0Eh)

00 nothing (ATN̅ was up) · 41 Save-Data-Pointer sent (IDI=1) ·
42 Disconnect message sent · 43 bus free — disconnected.

## Appendix I — target mode: init and phase engine

Nothing in §1/§2 changes: same GPIO map, same PIO engines (Send/Receive
Data honor the Control DM bits, so the SM1 burst engine and DMA channel
drive target-mode data phases exactly as initiator ones).

### Configuration

```
1. MR̅ pulse → interrupt 00h.
2. Own ID (00h) = our ID | EAF (| RAF only if B-specific firmware).
3. Command 00h (Reset) → interrupt 00h/01h.
4. Source ID (16h): ES=1 (respond to selection). ER only matters for
   initiator-role reconnects; DSP as needed.
5. Control (01h): DM=001 (burst) for data phases; HA=1 recommended so
   an initiator's ATN̅ interrupts long transfers; EDI/IDI per chaining
   strategy below.
6. Timeout (02h) still applies — to OUR Reselect attempts.
```

A selection by an initiator then arrives as interrupt **82h** (no ATN)
or **83h** (ATN) — or is absorbed automatically by a pending
Wait-for-Select-and-Receive.

### Two strategies, mirroring §4

**A. Combination (recommended): park in Wait-for-Select-and-Receive.**
Issue 0Ch when idle. The chip auto-handles selection, IDENTIFY (→ 0Fh,
tag → 1Ah[B]), and the whole COMMAND phase (CDB → 03h–0Eh, length from
the group code). One interrupt (13h/14h) delivers a parsed SCSI command.
Then:

* immediate service: Send Data (15h) / Receive Data (11h) with Transfer
  Count + burst DMA, then **0Dh** (status in CDB11, link bits in CDB12)
  → bus free, reissue 0Ch;
* disconnecting service (EDI=1): read-class CDBs auto-chain to **0Eh**
  (disconnect) before you even see them finish; do the medium work,
  then **0Ah/0Bh** to reselect and move data, with EDI/SCC chaining
  straight into 0Dh or 0Eh — a full disconnected READ costs ~3
  interrupts total;
* unknown CDB group (advanced): 87h pause → write length to 00h bits
  3:0 → reissue 0Ch.

**B. Manual (bring-up/debug): phase-at-a-time.** ES=1, wait for 82h/83h,
then drive the bus yourself — the key inversion vs initiator mode is
that **the target chooses the phases**: 12h Receive Message Out (if
83h) → 10h Receive Command → 11h/15h data → 14h Send Status → 16h Send
Message In (Command-Complete 00h) → 04h Disconnect. The opcode's low
bits set MSG/C/D directly (Appendix B); REQ̅/ACK̅ handshakes are still
entirely the chip's problem.

### Target-side rules that differ from §4

* **ATN̅ is the initiator's interrupt to us**: 84h (or HA-halted
  transfer, codes 14/24/44) means "stop and run Receive Message Out".
* Aborting a **Send**: stop feeding DRQ/DBR immediately after writing
  Abort. Aborting a **Receive**: keep draining until the interrupt
  (Appendix B, Abort row) — get this backwards and the FIFO wedges.
* Reselection (0A/0B/05h) arbitrates like selection and honors the
  same Timeout register; loss/timeout leaves phase = 00.
* IDENTIFY generation is automatic from 0Fh + ER/DOK; don't hand-build
  message bytes unless in strategy B (then it's just Send Message In).
* WFSR rejects LUNTAR Identifies unless the command is issued with SBT
  set (target-routine support).

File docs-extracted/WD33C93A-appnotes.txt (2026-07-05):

WESTERN DIGITAL CORPORATION
WD33C93A
DATA SHEET AND APPLICATION NOTES

WESTERN DIGITAL CORPORATION
NOVEMBER, 1990

Ii WES I ERN DIGITAL

Storage LSI Applications Note
U.S.A

WD Literature (800) 832-4778 USA
(800) 448-8470 Canada
(714) 932-4900lntemational
WD BBS:

(714) 756-8176
Canada:

WD Regional Offices
California
(415)' 335-2501
Georgia
(404) 394-1480
Illinois
(708) 882-8731
Massachusetts (508) 535-5914
New JefSey
(201) 285-1112
Texas
(214) 991-6800
(416) 566-4702
Ontario
Quebec
(514) 697-1532

Sept 15, 1990

PRODUCT: WD33C93A

Number 071-A

WD33C93A Application Note List
DescriPtion

Number

A (fected

E062-B

WD33C93.JAIB

Version Differences: All changes, additions, deletions, and
pan numbers for each of the released versions of the
WD33C93 SCSI Bus Interface Controller (SBIC) chip.

E031-A

WD33C93A

Data Sheet: Contains the data sheet for the WD33C93A SCSI
Bus Interface Controller (SBIC) chip.

E02S-A

WD33C93.JA

Conversion to the A version: List of design considerations
for converting to the WD33C93A from the non-A version.

E018-A

WD33C93A

Bug List: All known problems in the WD33C93A.

E022-A

WD33C93A

DRQ Bug, Rev C,D only: The DRQ signal may erroneously
deassert for a short time under some conditions

E024-A

WD33C93.JA

DRQ/DACK in Polled 1/0 mode: During polled I/O mode,
these lines should be held to a false state.

E033-A

WD33C9x

SCSI system design issues concerning bus noise: A paper on
the sources of noise on the SCSI bus and what to do about
them.

E039-A

WD33C93.JA

ACK assertion timing: ACK\ may be deasserted prior to
REQ\

E040-A

WD33C92/93.JA

Parity Errors during Select-and-Transfer: A parity error
may be masked by other interrupt conditions.

E042-A

WD33C92!3.JA

Synchronous/Asynchronous Transfers: Descriptions and issues concerning SBIC chip transfers.

International Offices:
Hong Kong 852-736-5123; Korea 822-554-0508; Munich 498-9922-0060; Ontario 416-566-4702; Paris 331-6985-5757;
Quebec 514-697-1532; Singapore 65-448-4700; Taiwan 886-2717-4775; Tokyo 813-791-2001; U.K. 443-7274-2955.
COpyright Western 0lglt811990
page' of 2

Storage LSI Applications Note # 071-A

E043-A

WD33C93A

Auxiliary Status Register Notes: Msc notes on use and function of the Auxiliary Status register of the SBIC chip.

E044-A

WD33C92/93.JA

Aborting a Wait-for-Select-and-Transfer: How to do it...

E04S-A

WD33C92/93.JA

Address Translation Times:

E046-A

WD33C92/93.JA

Unexpected Disconnect affects transfer count: Internal and
external transfer counts may differ in this circumstance.

E047-A

WD33C92/93.JA

Select-and-Transfer command flow chart:

E048-A

WD33C92/93.JA

Target Mode Vendor Unique CDBs: How the SBIG chip
handles various sizes of Command Descriptor Blocks ..

E049-A

WD33C92/93.JA

ALE Timing requirements: Maximum time length specification.

EOSO-A

WD33C92/93.JA

Initiator Mode Vendor Unique CDBs: How the SBIC chip
handles various sizes of Command Descriptor Blocks.

EOSI-A

WD33C92/93.JA

Target Mode- Delay of ATN Interrupt: Timing irregularity.

E06S-A

WD33C92/93-all

Host Transfer modes: Descriptions of the 4 modes of data
transfer between the SBICchip and the host.

E066-A

WD33C93A

Command/Interrupt Guide: A matrix of interrupts and commands for the WD33C93A.

E067-A

WD33C93A

SCSI Status Register: Description of logic orientation of
SCSI phase bits in the status register.

---.-- •.•.•..•..........--.•............ _......._-- ....--...----.--..-..--.--..--.-........_--_ ....---.........._-----E029-A

All

WD Sales Offices by Region: List ofWD world wide sales
offices listed by region of responsibility.

E030-A

All

North American Distributors and Resellers: List of all distributors in North America by state/province, list of all resellers.

E032-A

all

Decoding WD LSI part numbers: Top/bottom side part
number branding explained for LSI parts.

E070-A

All

Reserved Register Bits: Default programming of these bits
should always be with a value of zero (0).

Number E071-A
copyright Western Digital 1990

page2o'~

e:I WES I ERN DIGITAL

Storage LSI Applications Note
U.S.A

WD Literature (800) 832-4778 USA
(800) 448-8470 Canada
(714) 932-4900lntemational
WD BBS:

(714) 753-1234
Canada:

PRODUCT:

WD Regional Offices
(415) 335-2501

CalHomia
Georgia
Illinois
Massachusetts
New JeTSey
Texas
Ontario
Quebec

Model #: WD33C93JAlB
Manf #: 3393, 4393, 5393, 7393

(404) 394-1480
(708) 882-8731
(508) 535-5914
(201) 285-1112
(214) 991-6800
(416) 566-4702
(514) 697-1532

August 17,1990
Number E062·B

WD33C93 Version Differences
Current Sales: WD33C93A rev F
Future Sales: WD33C93B

Samples in 10/90, Production Quantity in 1/91
Note: This part will be sold in addition to the WD33C93A

WD33C93B
(differences from WD33C93A)
The WD33C93B is functional and performance improvement over the WD33C93A. The additions
to the WD33C93B are for SCSI 2 support and for improved system performance. The B part is
completely backwards compatible with the A part and may replace it in most applications with no
hardware or firmware modifications (see note for #5). Some minor changes are required to make
use of the additional functions of the B part.

1. Addition: Fast SCSI· The WD33C93B supports fast SCSI transfer rates of up to 10MB/s.
Bit 7 of the Synchronous Transfer register enables fast SCSI transfers. Clock frequencies of
between 16 and 20Mhz are required for this mode.
2. Addition: Tag Message Support·
a) Message Type: Bits 3,4 in the Destination ID register now indicate the type of tagged
message sent or received:
a 0 No Message
o 1 Simple Queue tag
1 0 Head of Queue tag
1 1 Ordered Queue tag
b) Queue Tag: A Queue Tag register has been added to hold the value of the second byte of
the tag messages associated with the Select-and-Transfer, Reselect-and-Transfer, and Waitfor-Select-and-Receive commands
3. Addition: FIFO Status Bit- Bit 3 of the Auxiliary Status register (FFE) now indicates
FIFO full or empty depending on the direction of transfer. The bit indicates FIFO empty
(FFE=1) when the J.lp is transferring data into the 12 byte FIFO. The bit indicates FIFO full
when the J.lp is reading from the FIFO. These enable the J.lp to transfer up to 12 bytes with-

Intematlonal Offices:
Hong Kong 852-736-5123; Korea 822-554-0508; Munich 498-9922-0060; Ontario 416-566-4702; Paris 331-6985-5757;
Quebec 514-697-1532; Singapore 65-448-4700; Taiwan 886-2717-4n5; Tokyo 813-791·2001; U.K. 443-7274-2955.

Copyright Westem Digital 1990

page' of 9

Storage LSI Applications Note # E062-S

out the need to poll the DBR output prior to each transfer.
4. Addition: Reselection Information: Bit 5 of the Target LUN register now indicates what
type of infonnation is in the lower bits of the Target LUN register:
..
o Logical Unit Number
1 Target Routine Number
5. Addition: Increased Target Mode Fault SCSI Bus Tolerance- The following features affect only the Target mode of operation. They are enabled by the RAF bit (fonnerly the Ern
bit) in the Own ID register. Applications which use this bit with the WD33C93A will have
to modify F/W accordingly:
a) Transfer Error Detection: When enabled, the WD33C93B will abort a Send or Receive
command with a 25h interrupt if it detects a possible transfer corruption caused by- noise on
the REQ and ACK signals.
b) Unexpected Bus Free Detection (new to Target mode, already exists in Initiator mode):
When enabled, the WD33C93B will generate either a 85h or 41h interrupt in the event of
unexpected disconnection. This is intended to catch noise on the SEL line which causes the
device to erroneously disconnect from the SCSI bus.
Note: If applications made use of the EIH bit in the WD33C93A, the F/W will have to be
modified to either disable the bit or accommodate the additional types of interrupts.
6. WD33C93B Number Reference:
Manr#
Model #
WD33C93B PL 00 02
WD33C93B 1M 00 02

7393KBIIPL
7393KBI11M

Description
40 pin Plastic DIP
44 pin PLCC

WD33C93B Differences fro WD33C93A
copyright Western Digital 1990

Number E062-S
page2of9

Storage LSI Applications Note # E062-B

(differences from WD33C93)

WD33C93A
1. HIW Addition: Faster Transfer Ratea) The WD33C93A can now transfer data at up to 5MB/s.

b) A burst DMA mode on the IlP side has been added to help accommodate higher data
bandwidths. Bit 5 of the Control register has been added to enable the DMA burst mode.
c) The maximum clock frequency has been increased to 20Mhz
d) Selectable dividers controlled by bits 7,6 in the Own ID register have been added to
manage transfer rate and arbitration timing.
2.

HIW Addition: Host Parity- The PLCC version of the WD33C93A now supports host
parity generating and checking.
a) Bit 5 (EHP) of the Own ID register has been added to enable the Host Parity feature.
b) Bit 4 (HHP) of the Control register has been added to enable Halt on Host Parity error.
c) Pin 11 of the PLCC is the J.1p data parity pin. This pin was "Test" and was not used
under normal operations.

3. HIW Addition: Extended FIFO- The WD33C93A internal data FIFO has been expanded
to 12 bytes from 5 bytes for the WD33C93. Bit 3 has been added to the offset counter in
, the Synchronous Transfer register to accommodate the increased FIFO size.
4.

HIW Change: Faster Execution Times- The command decode and algorithms of many
commands have been modified to greatly reduce controller overhead in both Target and Initiator modes.

5.

Cmd Addition: Send-Status-and-Command-Complete (ODh) - This target mode command has been added to the WD33C93A. This command first sends the status byte, as
specified in the CDB byte 11. This command will send a linked command complete
message. Linked command complete with flag is sent when bit 1 of CDB 12 is set. The
command will also chain to the command fetch portion of WAIT-for-Select-and-receive.

6.

Cmd Addition: Send-Disconnect-Message (OE) - This target mode command is used to
disconnect from the SCSI bus when the target expects to seek, find the fIrSt block, deal with
long tape operations, fill a buffer, etc.. The command sends the disconnect message, followed by a disconnect from the bus. If the ID! bit is set to one, a Save-Data-Pointer message is sent prior to the disconnect message.

7.

Cmd Addition: Set IDI bit (OF) - This command is used to set the IDI bit when a level II
command is in progress. This is needed since the register file is not accessible to the IlP at
that time.

WD33C93A Differences from WD33C93
copyright Western Digital 1990

Number E062-B
page30f9

Storage LSI Applications Note # E062-B

8.

Cmd Deletion: Transfer Pad Command: The Transfer Pad command is no longer supported in the WD33C93A.

9.

Cmd Deletion: Abort Command: The Abort command is no longer supported in the Initiator mode.

10. Feature Addition: Advanced Feature Control- Bit 3 (EAF) of the Own ID register has
been added to enable the following features:
a) Unexpected Reselection handling: Following a reselection by an unexpected target during a Select-andTransfer command, by an unexpected target during a Select-and-Transfer
command, or when idle and the Enable Reselection bit is 1, the WD33C93A will continue
and go fetch the identify message before interrupting the host.
b) Unknown Command Group size: In the Target mode, if the fIrst byte of the COB is an
opcode for an unknown command group (groups 2, 3, 4, 6, or 7), the device will interrupt
the host and ask for the total command length to be loaded into the Own ID register. This
feature is for Wait-for-Select-and-Receive for Select-and-Transfer only.
c) Data Phase Direction check: Bit 6 (DPD) has been added to the Destination ID register
to specify the expected direction of the SCSI data phase. This allows an error condition to
be generated if an incorrect data phase has been generated. This function is only applicable
to the operation of Select-and-Transfer commands.
d) Data Phase Direction Check Disable: Bit 5 (DF) has been added to the Destination ID
register to enable or disable both the Data Phase Direction check feature and the link from
Send-Status-and-Command-Complete to Wait-for-Select-and-Transfer. Note: This feature
is is only in the revision E and F parts.

11. Feature Addition: New Status Codes- The following status codes have been added:
a) WD33C93A Advanced Features Enabled- code 0000 0001: This code is returned after a
"Soft Reset" if the Enable Advanced Features (EAF) bit is set (bit 4, Own ID). The code
provides a means of verifying the presence of the A part.
b) Unexpected Reselection- code 0010 0111: This code is returned when an unexpected
reselection occurs during a Select-and-Transfer command, and indicates that the Target
LUN register contains a valid identify message.
c) Reselection- code 1000 0001: This code is returned when a reselection occurs when the
device is idling with Advanced features Mode enabled. The code indicates that the Data
register contains a valid identify message.
d) Device Pause- code 1000 0111: This code is returned when the device has paused to get
.
the command length in the Own ID register.

12. Feature Addition: Reselect-and-Transfer Cmd Enhancement: These commands may
now be resumed in the same manner as the initiator Select-and-Transfer commands. Also,

WD33C93A Differences from WD33C93
copyright Western Dlglta11990

Number E062-B
page4of9

Storage LSI Applications Note # E062-B

these commands may be chained to the new Send-Status-and Command-Complete and
Send-Disconnect-Message commands using the ED! bit in the control register, and the
command link select bit in the destination ID register.
13. Feature Addition: Wait-for-Select-and-Receive Cmd Enhancement: This command
may now be resumed in the same manner as the initiator Select-and-Transfer commands.
Also, this command may be chained to from the new Send-Status-and-Command-Complete
command. When ED! is set, this command will chain to the Send-Disconnect-Message
command if CDB byte 1 indicates a read command has been received.
14. Feature Addition: 20MHz clock rate: The input clock timings for the WD33C93A have
been changed from those listed in the WD33C93A data sheet, which specified a maximum
frequency of 16Mhz. The WD33C93A is now guaranteed to operate with a maximum
input clock frequency of 20MHz, and the revised timings are listed below:
Symbol

Characteristic

Min

Max

Units

Tcp

Clock Period

125

os

Teh

Clock High

Tel

Clock Low

50
20
20

··

Tep

·

·

:~

Clk

I(
~~

·
·

.. :
I

···

\

.~

.~~
Teh

os

..

\·

·

os

Tel

14.

15. Function Change- Single byte Transfers: The WD33C93 did not corrupt the Transfer
Count register during a Single-Byte-Transfer. This allowed a previous multi-byte operation
to be resumed without reloading the Transfer Count register after a Single-Byte-Transfer
command. This was an "undocumented feature" that ,no longer exists in the WD33C93A.
The Transfer Register is corrupted during a Single-Byte-Transfer and must be reloaded
after execution of that command.
16. Function Change- Phase Interrupts: The WD33C93 generates a Phase Change interrupt
following an Invalid Command interrupt. This is an unnecessary interrupt and basically an
unplanned "feature" of the WD33C93. The WD33C93A does not provide a Phase Change
interrupt following a Invalid Command interrupt

WD33C93A Differences from WD33C93
copyright Western Digital 1990

Number E062-B
page50f9

Storage LSI Applications Note /I E062-B

17. Msc Changes!Additions:
a) COB byte 11 register: This register is now also used to specify the status byte for ~end­
Status-and-Command-Complete commands
b) COB Byte 12 register: When the Flag bit (Bit 1) is 0 and 101 is I, Linked Command
Complete (message code = OAh) is sent during a Send-Status-and-Command-Complete
command. When this bit is 1 and 101 is I, Linked Command Complete with Flag (message
code =OBh) is sent during a Send-Status-and-Command-Complete command.
c) Target LUN register: This register can also contain the identify messag,e received during an unexpected reselection if advanced features are enabled.
d) Select Command Chain Control: Bit 7 (SCC) in the Destination 10 register has been
added to control which command is chained to when the data transfer is completed:

o Chain to Send-Status-and-Command-Complete
1 Chain to Send-Disconnect-Message
18. Rev E and F Changes only: The following changes were incorporated into revisions E
and F only of the WD33C93A part. Revision F is the current production part.
a) Enable Immediate Halt: Bit 5 (EIH) has been added to the Own 10 register. This
Target mode feature allows an immediate halt to occur on SCSI parity error or if ATN and
HA are both true instead of waiting for a 4k data boundary to occur.
b) Bit 5 (OF) has been added to the Destination 10 register to inhibit both the Data Phase
Direction check in the Advanced Features mode and the link from Send-Status-and-Command-Complete to Wait-for-Select -and-Transfer.
19. Register Difference Summary:
Register
Bit

WD33C93

3

a) Own 10 register:

WD33C93A

5
6,7

EAF- Enable Advanced Features
HHP- Halt on Host Parity error
EIH- Enable Immediate Halt
Xfr rate control

b) Control register:

5

DBA- DMA Burst Enable

c) Destination 10 register:

5
7

DF- Data Phase Dir Chk Enable
DPD- Data Phase Dir check
SCC- Select Command Chain

d) COB Byte 12 register:

1

LCC- Linked Command Control

e) Synch Xfr register

3

extra bit for 12 byte FIFO

4

6

WD33C93A Differences from WD33C93
copyright Western Digital 1990

Number E062-B
page6of9

Storage LSI Applications Note # E062-8

20. WD33C93A Incompatibilities when being used with a WD33C93 also on the SCSI
bus:
Performance optimization of both the internal microcode and the LSI design have resulted
in the following incompatibilities between the WD33C93A and the WD33C93:
.
a)
WD33C93 offset values: Due to timing differences between the two parts, the
WD33C93 offset must not be set to its maximum value of five during synchronous
transfers from the WD33C93A to the WD33C93. Any other offset value (0 through 4) may
be used.
b)
The WD33C93A checks for ATN\assertion before the start ofa data transfer. A Receive or Send command will halt if HA is set prior to the transfer of any data. The
WD33C93 allows a data transfer to occur before looking for ATN\
21. Function Change- 47h interrupt difference: The 47h interrupt in the WD33C93 is generated for a parity error in the status, message, or command bytes as well as for an incorrect
message. The 47h interrupt in the WD33C93A is only generated for a parity error in the
status byte. A 4Fh interrupt is now generated for a parity error in the message or command
bytes as well as for an incorrect message. The 43h interrupt is generated for all other parity
errors (data/command bytes).
To determine the cause of a 4Fh interrupt, issue a Transfer Information command. Either a
message byte (if an incorrect message) or a 43h interrupt (if a parity error) will result.
22. Function Change- Interrupt Difference: A 13h interrupt is generated after Selection has
occurred and an Abort command has been issued. The WD33C93 version issued a 23h interrupt.
23. Function Change- MR (Master Reset) Input: A hard reset (MR pin input) resets only
the Own ID register. The WD33C93 hard reset clears all registers. All other functions of
the hard reset are unchanged.
24. Synchronous Transfer Period change: The programming of the Synchronous Transfer
Period register has changed from the WD33C93. Previously it was necessary to program
the desired value+ 1. In the WD33C93A, the desired value is directly programmed (a period of 3 clocks is now programmed as "3" rather than "4" as in the WD33C93).
25. RCS pulse in WD-Bus mode: The WD33C93A no longer the RCS line to indicate a .
Ready to Transfer state. After the microprocessor issues a command to the SBIC chip, the
microprocessor should then assert DRQ when it is ready for data transfer. The SBIC will
sample the DRQ line and begin data transfer when ready.

WD33C93A Differences from WD33C93
copyright Western Digital 1990

Number E062-8
page 70t9

Storage LSI Applications Note # E062·B

26. Timing Differences:

WDJJC2JA

MaxLMiD

Mode
PIO

WDJJC2J

TDI.QH
TOHQL

DMA

40- 90
30

nomin-75
0

nsmin-max
nsmin

TSHWI
TSHRI
TSLWV
TSLRV
TWHDI
TOVRH
TRHDI

WD·Bus

0
0

no min spec
no min spec
30
30
20
20
0

nsmin
nsmin
nsmax
nsmax
nsmin
nsmin
nsmin

TOVAL
TRHDI
TALDI
TAHDI
TRHDI

Async-Target

0
replaced by TALDI
0
replaced by TRHDI
0

nsmin
nsmin
nsmin
nsmin
nsmin

TRHDI
TRHOI

Sync-Target
-Initiator

Simal
TRHDI

5

10

20
20
30
10
10

-Initiator

5
0
0

nsmin

27. ICC Specifcation change: The maximum specification for the supply current has been increased from 20ma to 36ma.
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

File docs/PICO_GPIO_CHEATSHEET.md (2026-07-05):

# Raspberry Pi Pico / Pico W / Pico 2 / Pico 2 W — GPIO Reference

## Quick Summary

| Board | Chip | Cores | PIO Blocks | PIO SM | SRAM | WiFi |
|---|---|---|---|---|---|---|
| Pico | RP2040 | 2× M0+ | 2 | 8 (4 ea) | 264 KB | No |
| Pico W | RP2040 | 2× M0+ | 2 | 8 | 264 KB | CYW43439 |
| Pico 2 | RP2350 | 2× M33 or 2× RISC-V | 3 | 12 (4 ea) | 520 KB | No |
| Pico 2 W | RP2350 | 2× M33 or 2× RISC-V | 3 | 12 | 520 KB | CYW43439 |

## Physical Pinout (40-pin DIP-style)

Boards are identical between Pico/Pico W and Pico 2/Pico 2 W.

```
           TOP  (USB port at top edge)
USB     +------------------------------+
        |  1: GP0  (pin 1 square pad)  |  40: VBUS (5V in)
        |  2: GP1                     |  39: VSYS (3.3V reg in)
        |  3: GND                     |  38: GND
        |  4: GP2                     |  37: 3V3_EN
        |  5: GP3                     |  36: 3V3_OUT
        |  6: GP4 (SDA1)              |  35: ADC_VREF (Volt)
        |  7: GP5 (SCL1)              |  34: GP28 (ADC2)
        |  8: GND                     |  33: GND (AGND)
        |  9: GP6                     |  32: GP27 (ADC1)
        | 10: GP7                     |  31: GP26 (ADC0)
        | 11: GP8                     |  30: RUN
        | 12: GP9                     |  29: GP22
        | 13: GND                     |  28: GND
        | 14: GP10                    |  27: GP21
        | 15: GP11                    |  26: GP20
        | 16: GP12                    |  25: GP19
        | 17: GP13                    |  24: GP18
        | 18: GND                     |  23: GND
        | 19: GP14                    |  22: GP17
        | 20: GP15                    |  21: GP16
        +------------------------------+
```

### Power Pins

| Pin | Name | Voltage | Notes |
|-----|---|---|---|
| 40 | VBUS | 5V | USB input, powers board when USB plugged |
| 39 | VSYS | 1.8–5.5V | Main system input to voltage regulator |
| 37 | 3V3_EN | — | Pull high to enable 3.3V reg; pull low to reset |
| 36 | 3V3_OUT | 3.3V | Regulated 3.3V output, up to 300 mA |
| 35 | ADC_VREF | 3.3V | ADC voltage reference |
| 30 | RUN | — | Reset pin, active low |
| 3,8,13,18,23,28,33,38 | GND | 0V | Ground |

### Wireless (W variants only)

| GPIO | Function | Direction | Notes |
|---|---|---|---|
| GPIO23 | CYW_SPI_CS | Output | SPI CS to wireless chip |
| GPIO24 | CYW_SPI_MISO | Input | SPI MISO from wireless chip |
| GPIO25 | CYW_SPI_CLK | Output | SPI clock to wireless chip |
| GPIO29 | CYW_SPI_MOSI | Output | SPI MOSI to wireless chip |
| — | CYW_DATA_OUT | — | OOB out-of-band data |
| — | CYW_DATA_IN | — | OOB in-band data |
| — | CYW_WAKE | Output | Wake the wireless chip |

**On W variants**, GPIO23, GPIO24, GPIO25, GPIO29 are **not available** for general use — they are connected to the CYW43439 WiFi/Bluetooth chip via SPI (CS, MISO, CLK, MOSI respectively).

On W variants, GP0 is NOT one of the WiFi-connected pins, but note that the CYW43439 on Pico W communicates via SPI on GP23–GP25 + GP29. These cannot be used for other purposes while WiFi is active.

### Pico 2 / RP2350 additional notes

- RP2350 has 48 GPIOs (0–47), but **only GPIO0–28 are physically broken out** on the Pico 2 board (same 40-pin layout).
- GPIO29 is used by the ADC for VSYS measurement (pin 39) — available as ADC3 on all boards.
- RP2350 has **3 PIO blocks** with 4 state machines each = 12 total (RP2040 has 2 blocks = 8 total).

## GPIO Function Table

All 26 usable GPIOs (GP0–GP28, except GP23–G25, GP29) on all Pico boards.

GPIO defaults after reset: **high-impedance input** (SIO function F5 selected). The functions below are **alternative functions available via the GPIO function select register** (F1 = GPIO_CTRL_FUNCSEL).
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

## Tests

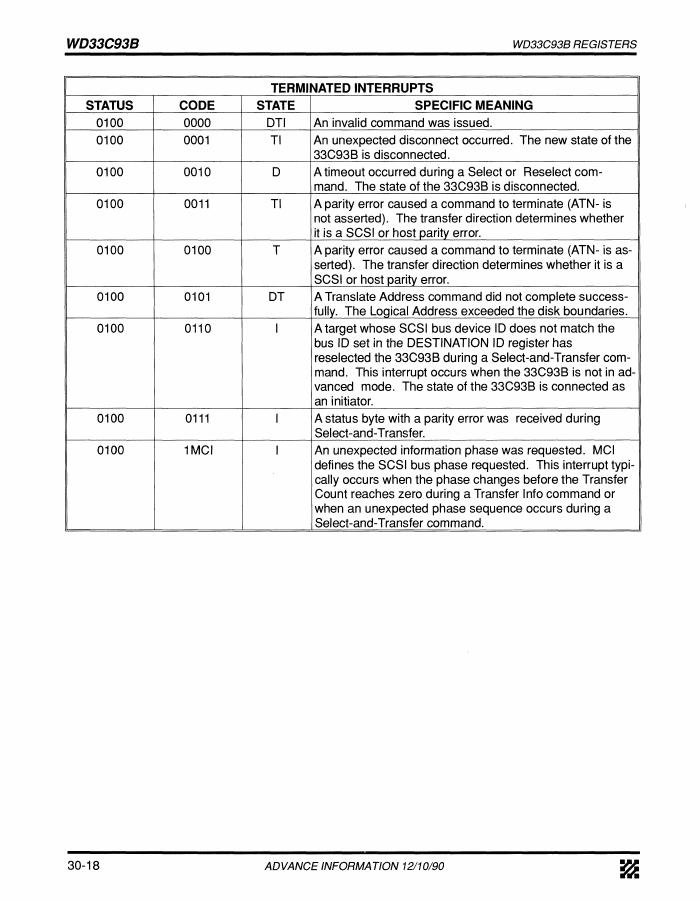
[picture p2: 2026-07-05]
session/6e23006d-864c-4742-9457-511b329ae541/tool-results/pdf-65a604f8-ed90-4112-a40f-88b8c4090dca/page-23.jpg

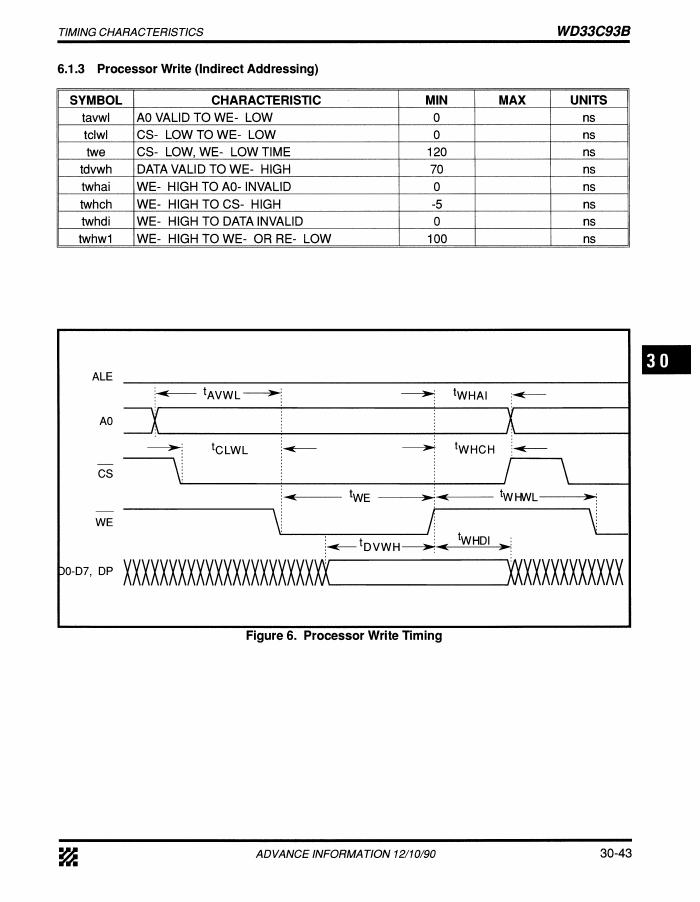
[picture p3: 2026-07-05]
session/6e23006d-864c-4742-9457-511b329ae541/tool-results/pdf-f0ce1383-339b-4223-b203-ed40b8cf3822/page-48.jpg

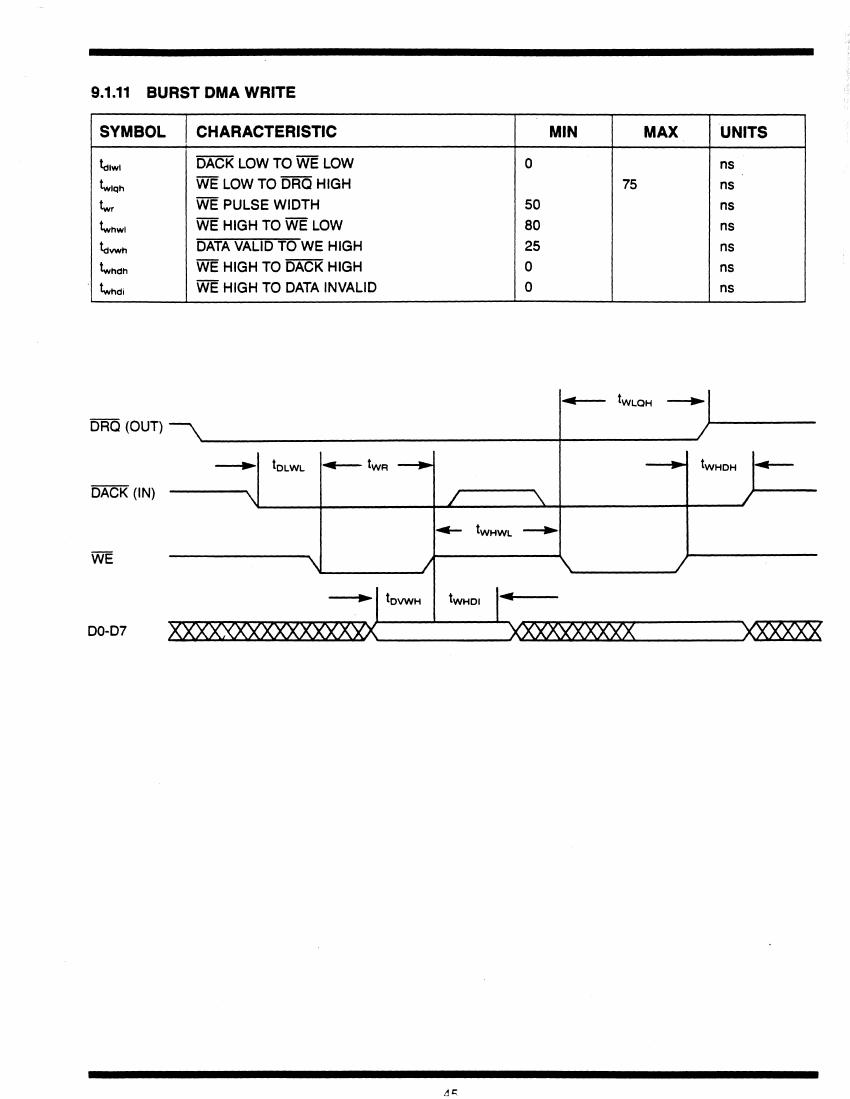
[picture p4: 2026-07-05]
session/6e23006d-864c-4742-9457-511b329ae541/tool-results/pdf-ae54f759-53c9-47eb-b404-9563ce885096/page-60.jpg

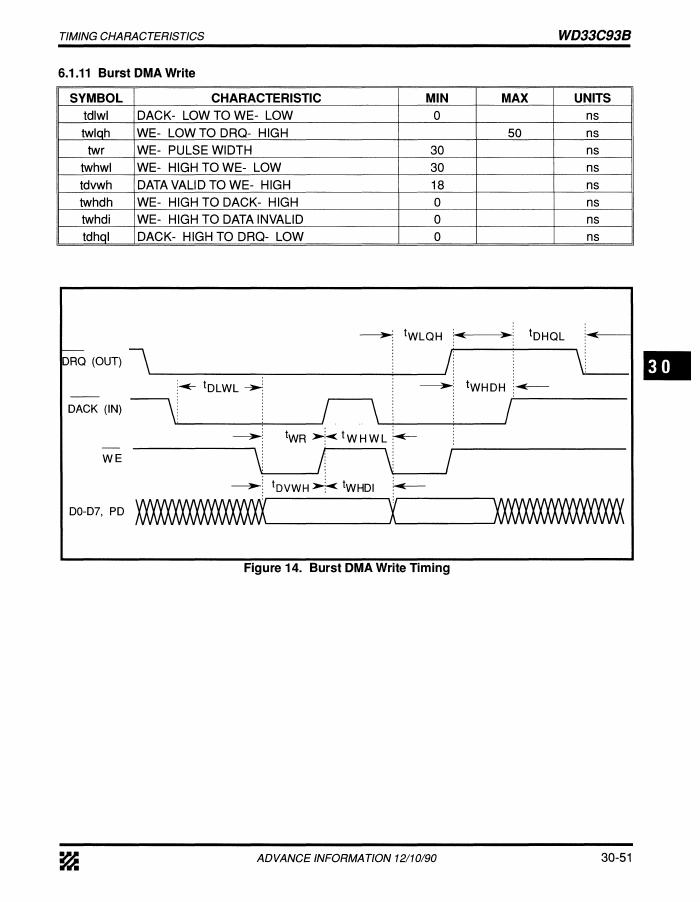
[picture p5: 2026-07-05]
session/6e23006d-864c-4742-9457-511b329ae541/tool-results/pdf-75530337-e969-497a-a053-e1fab07b60f2/page-56.jpg

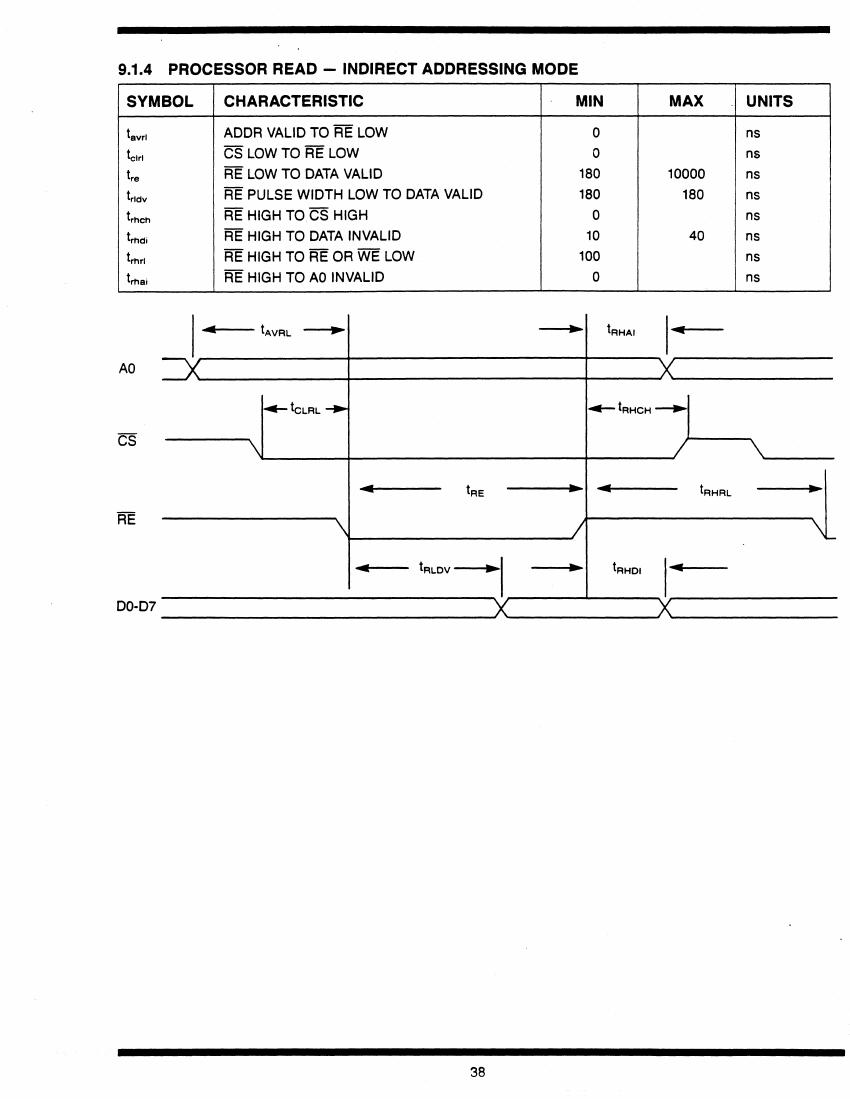
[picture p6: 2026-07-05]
session/6e23006d-864c-4742-9457-511b329ae541/tool-results/pdf-c38d6c2b-facc-4b9f-be11-fba2e335aeba/page-53.jpg

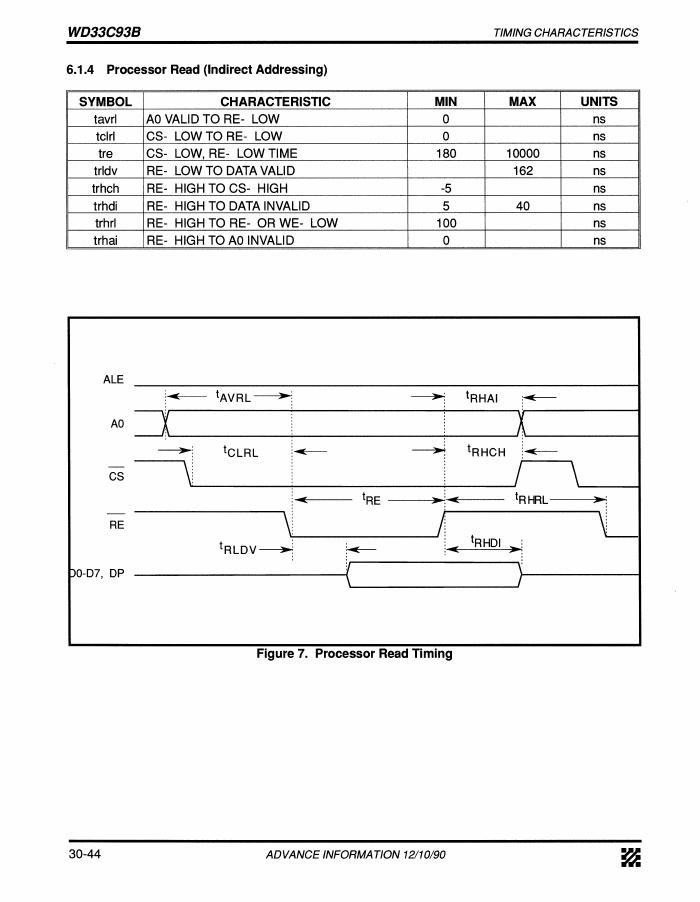
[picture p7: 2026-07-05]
session/6e23006d-864c-4742-9457-511b329ae541/tool-results/pdf-f0ce1383-339b-4223-b203-ed40b8cf3822/page-49.jpg

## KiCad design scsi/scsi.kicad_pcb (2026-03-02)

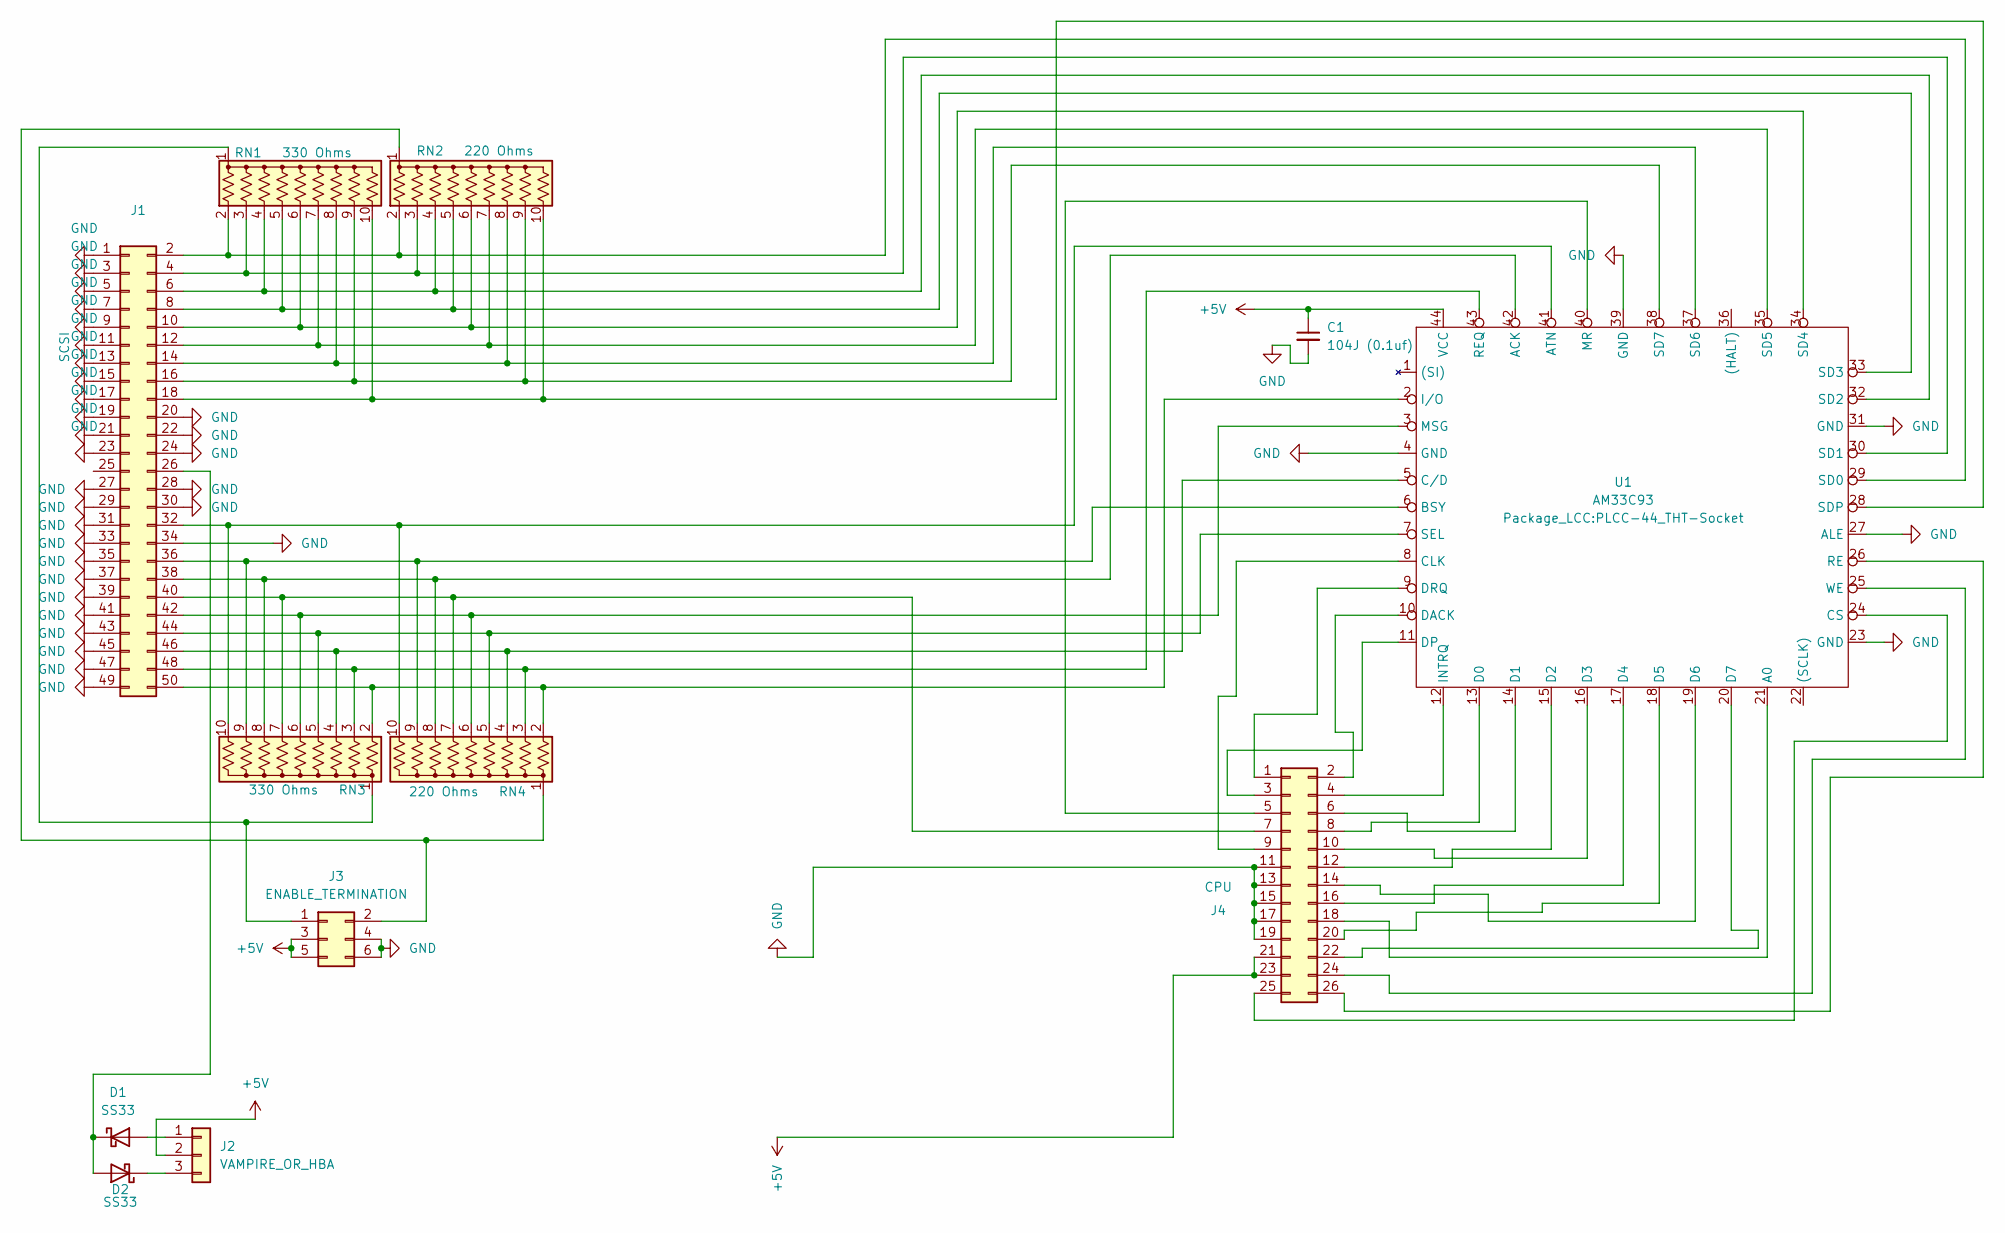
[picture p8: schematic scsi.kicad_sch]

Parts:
C1: 104J (0.1uf); C_Disc_D5.0mm_W2.5mm_P5.00mm
D1, D2: SS33; D_SMB-SMC_Universal_Handsoldering
J1: SCSI; IDC-Header_2x25_P2.54mm_Vertical
J2: VAMPIRE_OR_HBA; PinSocket_1x03_P2.54mm_Vertical
J3: ENABLE_TERMINATION; PinHeader_2x03_P2.54mm_Vertical
J4: CPU; PinHeader_2x13_P2.54mm_Vertical
RN1, RN3: 330 Ohms; R_Array_SIP10
RN2, RN4: 220 Ohms; R_Array_SIP10
U1: AM33C93; PLCC-44_THT-Socket

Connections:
+5V: C1.1, J2.2, J3.3, J3.5, J4.21, J4.23, U1.44 (VCC)
GND: C1.2, J1.1, J1.3, J1.5, J1.7, J1.9, J1.11, J1.13, J1.15, J1.17, J1.19, J1.20, J1.21, J1.22, J1.23, J1.24, J1.27, J1.28, J1.29, J1.30, J1.31, J1.33, J1.34, J1.35, J1.37, J1.39, J1.41, J1.43, J1.45, J1.47, J1.49, J3.4, J3.6, J4.11, J4.13, J4.15, J4.17, J4.19, U1.4 (GND), U1.23 (GND), U1.27 (ALE), U1.31 (GND), U1.39 (GND)
unnamed: D1.2 (A), J2.1
unnamed: D1.1 (K), D2.2 (A), J1.26
unnamed: D2.1 (K), J2.3
unnamed: J1.2, RN1.2 (R1), RN2.2 (R1), U1.29 (SD0)
unnamed: J1.4, RN1.3 (R2), RN2.3 (R2), U1.30 (SD1)
unnamed: J1.6, RN1.4 (R3), RN2.4 (R3), U1.32 (SD2)
unnamed: J1.8, RN1.5 (R4), RN2.5 (R4), U1.33 (SD3)
unnamed: J1.10, RN1.6 (R5), RN2.6 (R5), U1.34 (SD4)
unnamed: J1.12, RN1.7 (R6), RN2.7 (R6), U1.35 (SD5)
unnamed: J1.14, RN1.8 (R7), RN2.8 (R7), U1.37 (SD6)
unnamed: J1.16, RN1.9 (R8), RN2.9 (R8), U1.38 (SD7)
unnamed: J1.18, RN1.10 (R9), RN2.10 (R9), U1.28 (SDP)
unnamed: J1.32, RN3.10 (R9), RN4.10 (R9), U1.41 (ATN)
unnamed: J1.36, RN3.9 (R8), RN4.9 (R8), U1.6 (BSY)
unnamed: J1.38, RN3.8 (R7), RN4.8 (R7), U1.42 (ACK)
unnamed: J1.40, J4.7, RN3.7 (R6), RN4.7 (R6)
unnamed: J1.42, RN3.6 (R5), RN4.6 (R5), U1.3 (MSG)
unnamed: J1.44, RN3.5 (R4), RN4.5 (R4), U1.7 (SEL)
unnamed: J1.46, RN3.4 (R3), RN4.4 (R3), U1.5 (C/D)
unnamed: J1.48, RN3.3 (R2), RN4.3 (R2), U1.43 (REQ)
unnamed: J1.50, RN3.2 (R1), RN4.2 (R1), U1.2 (I/O)
unnamed: J3.1, RN1.1 (common), RN3.1 (common)
unnamed: J3.2, RN2.1 (common), RN4.1 (common)
unnamed: J4.1, U1.9 (DRQ)
unnamed: J4.2, U1.10 (DACK)
unnamed: J4.3, U1.11 (DP)
unnamed: J4.4, U1.12 (INTRQ)
unnamed: J4.5, U1.40 (MR)
unnamed: J4.6, U1.14 (D1)
unnamed: J4.8, U1.13 (D0)
unnamed: J4.9, U1.8 (CLK)
unnamed: J4.10, U1.16 (D3)
unnamed: J4.12, U1.15 (D2)
unnamed: J4.14, U1.19 (D6)
unnamed: J4.16, U1.17 (D4)
unnamed: J4.18, U1.21 (A0)
unnamed: J4.20, U1.18 (D5)
unnamed: J4.22, U1.20 (D7)
unnamed: J4.24, U1.25 (WE)
unnamed: J4.25, U1.24 (CS)
unnamed: J4.26, U1.26 (RE)

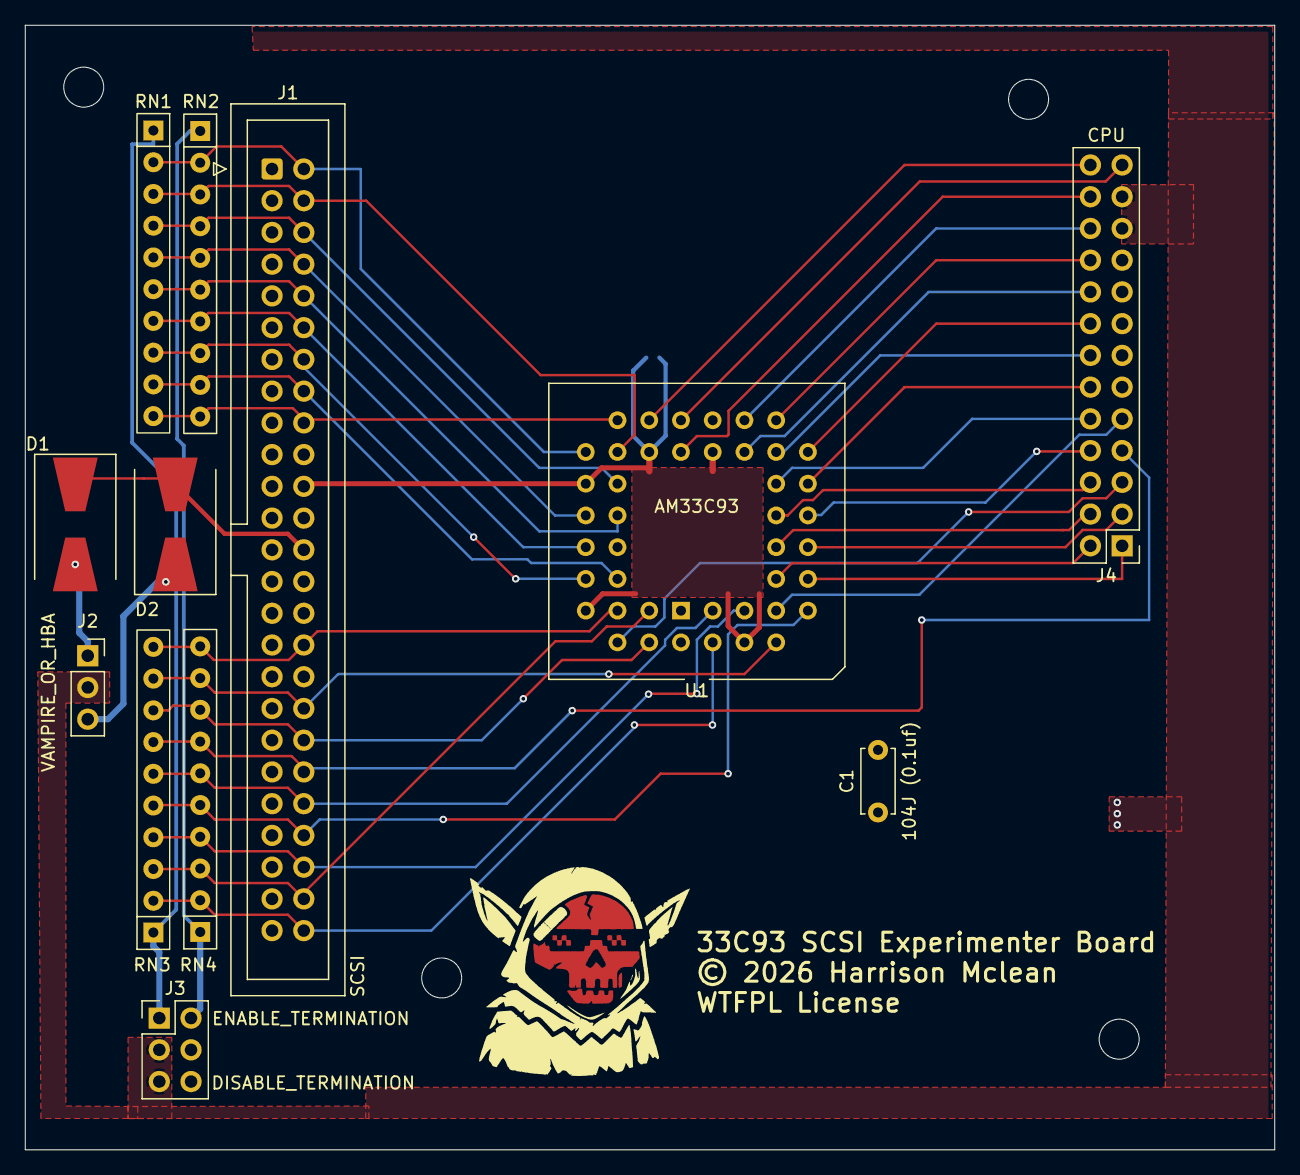
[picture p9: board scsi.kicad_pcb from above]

Board: 2 copper layers, 100.0 x 90.0 mm, 12 parts (0 on the bottom side), 43 nets.

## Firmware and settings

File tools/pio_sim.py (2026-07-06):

#!/usr/bin/env python3
"""Stage-3 PIO verification: behavioral simulation against a mock 33C93A.

check_pio_timing.py (stage 1) proves the strobe *timing* meets the
datasheet; assemble_pio.py (stage 2) proves the source *assembles*.
Neither proves the programs implement the *protocol*: that the bits SM0
puts on D0–7/A0 while WE̅ is low actually drive the indirect-addressing
state machine of the chip (WD33C93A app notes §6.2.2 / B datasheet
§3.1.2), that INTRQ rises and falls when the datasheet says (§9.1.13),
or that SM1's DACK̅+strobe bursts move bytes in order (§9.1.11/9.1.12;
B §6.1.11/6.1.12). This tool closes that gap:

  1. Assembles the ```pioasm blocks in ARCHITECTURE.md to real 16-bit
     PIO machine words with a built-in encoder, and cross-checks the
     sbic_bus result word-for-word against the pioasm-2.2.0 output
     captured in session/6e23006d-*/ (golden reference embedded below).
  2. Executes those *words* — decode included, so a mis-encoded field
     is an execution failure, not a parse difference — in a
     cycle-accurate PIO SM model: OSR/ISR shifts, autopush/autopull,
     FIFO stalls, side-set-on-first-cycle, delay cycles, pindirs, and
     the 2-sys_clk input-synchronizer age on `in pins` / `wait gpio`.
  3. Wires the pins (per the ARCHITECTURE.md §1 GPIO map) to a mock
     WD33C93A register file that enforces the datasheet at every edge:
     strobe min/max widths, recovery, data setup/valid windows, bus
     contention, DACK̅-vs-CS̅ exclusion (errata E024), the indirect
     Address-register protocol with its auto-increment exceptions
     (Aux Status / Data 19h / Command 18h), INTRQ set/clear semantics,
     the 7 µs LCI rule, and DRQ̅ burst handshaking.

Timing constants (SM divider, sys_clk, datasheet minima) intentionally
mirror check_pio_timing.py so the two stages cannot silently diverge.

Tests (run all; exit 0 = pass):
  golden-encoding    assembler output == pioasm 2.2.0 words from session
  init-sequence      SM0 full init: MR̅ pulse → wait INTRQ → read SCSI
                     Status (INTRQ must clear) → write Own ID → read back
  aux-status         A0=0 read returns Aux Status, Address reg untouched
  auto-increment     CDB regs 03h–06h written 1+N cycles, read back;
                     Data (19h) does NOT auto-increment
  lci-7us-rule       command <7 µs after status read ignored + LCI;
                     ≥7 µs accepted (soft reset → interrupt 00h)
  burst-in           SM1 DRQ̅/DACK̅ read burst (A variant): order,
                     timing, CS̅ high
  burst-out          SM1 write burst (A variant): order, setup, width
  golden-burst-pipeline  B variant: 12 bytes with pipelined validity
                     (first ≤50 ns from DACK̅↓, later ≤80 ns from prev
                     RE̅↑) and every inter-byte gap ≥ 80 ns
  variant-probe      soft reset with EAF+RAF: CDB1 = microcode rev on
                     a B, 0 on an A (Appendix E item 9)
  fifo-stall-hazard  >4 un-drained SM0 reads → `in` stalls with RE̅ low
                     → mock must flag the tRE ≤ 10 µs violation

The mock's burst timing is chip-variant aware (chip_variant="A"|"B" on
Bus/Sim/MockWD33C93A): A enforces §9.1.11/9.1.12 with every byte
independently valid tRLDV after RE̅↓; B enforces §6.1.11/6.1.12 with
the pipelined read model and the faster strobe/setup minima.

Run from the repo root:
    python3 tools/pio_sim.py [-v]
"""

import argparse
import re
import sys

DOC = "ARCHITECTURE.md"

# --- clocking (same numbers as check_pio_timing.py) --------------------
F_SYS = 120e6
SM_DIV = 5
T = 1e9 / (F_SYS / SM_DIV)      # ns per SM cycle (41.67)
SYNC = 2 * (1e9 / F_SYS)        # input-synchronizer age, ns (16.7)

# --- GPIO map (ARCHITECTURE.md section 1) -------------------------------
D0 = 0                          # GP0-7  D0-D7
A0 = 8                          # GP8
CS = 9                          # GP9   CS-   (active low)
WE = 10                         # GP10  WE-
RE = 11                         # GP11  RE-
DACK = 12                       # GP12  DACK-
MR = 14                         # GP14  MR-
INTRQ = 15                      # GP15  INTRQ (active HIGH)
DRQ = 16                        # GP16  DRQ-  (active low, 1k pull-up)

# --- datasheet limits, ns (A app notes 9.1.3/9.1.4/9.1.11/9.1.12/9.1.13;
#     Appendix C of ARCHITECTURE.md) -------------------------------------
IND_TWE_MIN = 120.0         # WE- pulse width
IND_TDVWH_MIN = 70.0        # data valid to WE- high
IND_TRE_MIN = 180.0         # RE- pulse width
IND_TRE_MAX = 10_000.0      # RE- pulse width max (the FIFO-stall trap)
IND_TRLDV = 180.0           # RE- low to data valid (chip drive delay)
IND_RECOVERY = 100.0        # tWHWL / tRHRL
# Burst DMA limits are chip-variant specific (A app notes 9.1.11/9.1.12
# vs B datasheet 6.1.11/6.1.12). A treats every read byte independently
# (data valid <= 50 ns from RE- low); B is *pipelined*: the first byte
# is valid <= 50 ns from DACK- low (tDLDV), each later byte <= 80 ns
# from the PREVIOUS RE- high (tRHDV) -- RE- just advances the FIFO.
BURST_SPEC = {
    "A": {"trd": 80.0, "twr": 50.0, "setup": 25.0, "recovery": 80.0,
          "rldv": 50.0, "pipelined": False},
    "B": {"trd": 30.0, "twr": 30.0, "setup": 18.0, "recovery": 30.0,
          "first_dv": 50.0, "rhdv": 80.0, "pipelined": True},
}
BST_PIPE_GAP = 80.0         # design guarantee: prev RE-hi -> next RE-lo
                            # >= 80 ns so B data is stable pre-strobe
MICROCODE_REV = 0x0D        # mock B: CDB1 after soft reset with RAF=1
MR_MIN = 1_000.0            # MR- pulse width
LCI_WINDOW = 7_000.0        # 7 us command lockout after status read
RESET_DONE_NS = 5_000.0     # mock: MR-/soft-reset completion latency

# Golden sbic_bus words: pioasm 2.2.0 output captured in
# session/6e23006d-864c-4742-9457-511b329ae541.jsonl (sbic_bus.pio.h).
GOLDEN_SBIC_BUS = [
    0x9CA0, 0x7C09, 0x7C21, 0x1C2A, 0xBCE3, 0x7C88, 0xAB42,
    0xA942, 0x4808, 0x1D00, 0xBCEB, 0x7C88, 0xB342, 0x1D00,
]

# Register file constants
REG_OWN_ID = 0x00
REG_CONTROL = 0x01
REG_CDB1 = 0x03
REG_SCSI_STATUS = 0x17
REG_COMMAND = 0x18
REG_DATA = 0x19

CMD_RESET = 0x00
CMD_TRANSFER_INFO = 0x20

# TX-word encoding (ARCHITECTURE.md section 3 C API)
def XW(a0, d):
    return ((a0 & 1) << 8) | (d & 0xFF)

def XR(a0):
    return (1 << 9) | ((a0 & 1) << 8)


# ========================================================================
# pioasm subset assembler (validated against GOLDEN_SBIC_BUS)
# ========================================================================

_JMP_COND = {"": 0, "!x": 1, "x--": 2, "!y": 3, "y--": 4,
             "x!=y": 5, "pin": 6, "!osre": 7}
_OUT_DEST = {"pins": 0, "x": 1, "y": 2, "null": 3, "pindirs": 4,
             "pc": 5, "isr": 6, "exec": 7}
_IN_SRC = {"pins": 0, "x": 1, "y": 2, "null": 3, "isr": 6, "osr": 7}
_MOV_DEST = {"pins": 0, "x": 1, "y": 2, "exec": 4, "pc": 5,
             "isr": 6, "osr": 7}
_MOV_SRC = {"pins": 0, "x": 1, "y": 2, "null": 3, "status": 5,
            "isr": 6, "osr": 7}
_WAIT_SRC = {"gpio": 0, "pin": 1, "irq": 2}

_LINE_RE = re.compile(
    r"^(?:(\w+):\s*)?(\S.*?)?\s*(?:side\s+(0b[01]+|\d+))?\s*(?:\[(\d+)\])?$")


def assemble(source, side_bits=3):
    """Assemble the pioasm subset used by ARCHITECTURE.md -> word list."""
    labels, body = {}, []
    for raw in source.splitlines():
        line = raw.split(";")[0].strip()
        if not line or line.startswith("."):
            continue
        m = _LINE_RE.match(line)
        label, instr, side, delay = m.groups()
        if label:
            labels[label] = len(body)
        if instr:
            if side is None:
                raise ValueError(f"missing side annotation: {line!r}")
            body.append((instr.strip(), int(side, 0), int(delay or 0)))

    delay_bits = 5 - side_bits
    if any(d >= (1 << delay_bits) for _, _, d in body):
        raise ValueError("delay exceeds field budget")

    words = []
    for instr, side, delay in body:
        parts = instr.replace(",", " ").split()
        op, args = parts[0], parts[1:]
        if op == "nop":
            word = 0xA000 | (_MOV_DEST["y"] << 5) | _MOV_SRC["y"]
        elif op == "pull":
            word = 0x8000 | (1 << 7) | (("block" in args) << 5)
        elif op == "push":
            word = 0x8000 | (("block" in args) << 5)
        elif op == "jmp":
            cond = args[0] if len(args) == 2 else ""
            target = args[-1]
            addr = labels[target] if target in labels else int(target, 0)
            word = 0x0000 | (_JMP_COND[cond] << 5) | addr
        elif op == "out":
            count = int(args[1], 0)
            word = 0x6000 | (_OUT_DEST[args[0]] << 5) | (count & 0x1F)
        elif op == "in":
            count = int(args[1], 0)
            word = 0x4000 | (_IN_SRC[args[0]] << 5) | (count & 0x1F)
        elif op == "mov":
            src = args[1]
            invert = src.startswith("~")
            word = (0xA000 | (_MOV_DEST[args[0]] << 5)
                    | (0b01 << 3 if invert else 0)
                    | _MOV_SRC[src.lstrip("~!")])
        elif op == "wait":
            pol, src, idx = int(args[0], 0), args[1], int(args[2], 0)
            word = 0x2000 | (pol << 7) | (_WAIT_SRC[src] << 5) | idx
        else:
            raise ValueError(f"unsupported instruction: {instr!r}")
        word |= (side << (8 + delay_bits)) | (delay << 8)
        words.append(word)
    return words


def extract_programs(doc_text):
    """-> {name: (source, words)} from the ```pioasm blocks."""
    programs = {}
    for block in re.findall(r"```pioasm\n(.*?)```", doc_text, re.S):
        name = re.search(r"\.program (\S+)", block).group(1)
        programs[name] = (block, assemble(block))
    return programs


# ========================================================================
# Pin bus with timestamped history (for synchronizer-delayed sampling)
# ========================================================================

class Bus:
    """Resolves SM outputs, firmware GPIOs and chip drivers per pin.

    Precedence per pin: at most one driver may be active (contention is
    a logged violation).  Undriven pins float to their pull value.
    """

    def __init__(self, chip_variant="A"):
        assert chip_variant in ("A", "B")
        self.chip_variant = chip_variant
        self.pull = {DRQ: 1}                # 1k external pull-up on DRQ-
        self.sm_out = {}                    # pin -> level (output register)
        self.sm_dir = {}                    # pin -> bool driven by SM
        self.fw_out = {}                    # pin -> level or absent
        self.chip_out = {}                  # pin -> level or absent
        self.history = {}                   # pin -> [(t, level)]
        self.violations = []
        self.listeners = []                 # f(t, pin, old, new)
        self._levels = {}

    def violation(self, t, msg):
        self.violations.append((t, msg))

    def level(self, pin):
        drivers = []
        if self.sm_dir.get(pin):
            drivers.append(self.sm_out.get(pin, 0))
        if pin in self.fw_out:
            drivers.append(self.fw_out[pin])
        if pin in self.chip_out:
            drivers.append(self.chip_out[pin])
        if not drivers:
            return self.pull.get(pin, 1)    # float high (terminated bus)
        return drivers[0]

    def contention(self, pin):
        n = (bool(self.sm_dir.get(pin)) + (pin in self.fw_out)
             + (pin in self.chip_out))
        return n > 1

    def commit(self, t):
        """Recompute all pins; record transitions and notify listeners.

        Two-phase: all same-cycle level changes land in _levels/history
        first, THEN listeners fire -- so a listener judging pin X (e.g.
        "was DACK- low when RE- fell?") sees every co-asserted side-set
        bit of the same instruction, regardless of GPIO numbering.
        """
        pins = (set(self.sm_out) | set(self.sm_dir) | set(self.fw_out)
                | set(self.chip_out) | set(self.pull) | set(self._levels))
        changed = []
        for pin in sorted(pins):
            if self.contention(pin):
                self.violation(t, f"bus contention on GP{pin}")
            new = self.level(pin)
            old = self._levels.get(pin, self.pull.get(pin, 1))
            if new != old or pin not in self._levels:
                self._levels[pin] = new
                self.history.setdefault(pin, []).append((t, new))
                changed.append((pin, old, new))
        for pin, old, new in changed:
            for f in self.listeners:
                f(t, pin, old, new)

    def sampled(self, pin, t):
        """Pin level as seen through the 2-flop synchronizer at time t."""
        hist = self.history.get(pin, [])
        val = self.pull.get(pin, 1)
        for ht, hv in hist:
            if ht <= t:
                val = hv
            else:
                break
        return val

    def now(self, pin):
        return self._levels.get(pin, self.pull.get(pin, 1))

    def data_byte_now(self):
        return sum(self.now(D0 + i) << i for i in range(8))

    def data_byte_sampled(self, t):
        return sum(self.sampled(D0 + i, t) << i for i in range(8))


# ========================================================================
# PIO state machine: executes 16-bit words, cycle-accurate
# ========================================================================

class StateMachine:
    def __init__(self, bus, words, *, name, sideset_base, out_base,
                 out_count, in_base, side_bits=3,
                 out_shift_right=True, autopull=False, pull_thresh=32,
                 in_shift_right=False, autopush=False, push_thresh=8):
        self.bus = bus
        self.name = name
        self.words = words
        self.sideset_base = sideset_base
        self.side_bits = side_bits
        self.delay_bits = 5 - side_bits
        self.out_base, self.out_count = out_base, out_count
        self.in_base = in_base
        self.out_shift_right = out_shift_right
        self.autopull, self.pull_thresh = autopull, pull_thresh
        self.in_shift_right = in_shift_right
        self.autopush, self.push_thresh = autopush, push_thresh
        self.pc = 0
        self.x = self.y = 0
        self.osr, self.osr_count = 0, 32        # 32 = empty (all shifted)
        self.isr, self.isr_count = 0, 0
        self.tx, self.rx = [], []               # FIFOs, depth 4
        self.delay_left = 0
        self.enabled = True

    # -- pin helpers -----------------------------------------------------
    def _apply_sideset(self, side):
        for i in range(self.side_bits):
            pin = self.sideset_base + i
            self.bus.sm_out[pin] = (side >> i) & 1
            self.bus.sm_dir[pin] = True

    def set_pins(self, base, count, value, dirs=False):
        for i in range(count):
            pin = base + i
            if dirs:
                self.bus.sm_dir[pin] = bool((value >> i) & 1)
            else:
                self.bus.sm_out[pin] = (value >> i) & 1

    # -- OSR/ISR ----------------------------------------------------------
    def _out_shift(self, n):
        if self.out_shift_right:
            val = self.osr & ((1 << n) - 1)
            self.osr >>= n
        else:
            val = (self.osr >> (32 - n)) & ((1 << n) - 1)
            self.osr = (self.osr << n) & 0xFFFFFFFF
        self.osr_count += n
        return val

    def step(self, t):
        """Execute one SM cycle beginning at time t (ns)."""
        if not self.enabled:
            return
        if self.delay_left:                     # burning delay cycles
            self.delay_left -= 1
            return

        word = self.words[self.pc]
        side = (word >> (8 + self.delay_bits)) & ((1 << self.side_bits) - 1)
        delay = (word >> 8) & ((1 << self.delay_bits) - 1)
        opc = word >> 13
        rest = word & 0xFF

        # side-set takes effect on the first cycle, stall or not
        self._apply_sideset(side)
        self.bus.commit(t)

        stalled = False
        advance = True

        if opc == 0b000:                        # JMP
            cond, addr = (rest >> 5) & 7, word & 0x1F
            take = {0: True, 1: self.x == 0, 3: self.y == 0}.get(cond)
            if cond == 2:
                take, self.x = self.x != 0, (self.x - 1) & 0xFFFFFFFF
            if cond == 4:
                take, self.y = self.y != 0, (self.y - 1) & 0xFFFFFFFF
            if cond == 5:
                take = self.x != self.y
            if cond == 6:
                take = self.bus.sampled(0, t - SYNC) == 1  # unused here
            self.pc = addr if take else self.pc + 1
            advance = False
        elif opc == 0b001:                      # WAIT
            pol, src, idx = (rest >> 7) & 1, (rest >> 5) & 3, word & 0x1F
            assert src == 0, "only WAIT ... GPIO modeled"
            if self.bus.sampled(idx, t - SYNC) != pol:
                stalled = True
        elif opc == 0b010:                      # IN
            src, n = (rest >> 5) & 7, (word & 0x1F) or 32
            assert src == 0, "only IN PINS modeled"
            # autopush full-RX stall happens *before* the shift commits
            if self.autopush and self.isr_count + n >= self.push_thresh \
                    and len(self.rx) >= 4:
                stalled = True
            else:
                val = 0
                for i in range(n):
                    val |= self.bus.sampled(self.in_base + i, t - SYNC) << i
                if self.in_shift_right:
                    self.isr = (self.isr >> n) | (val << (32 - n))
                else:
                    self.isr = ((self.isr << n) | val) & 0xFFFFFFFF
                self.isr_count += n
                if self.autopush and self.isr_count >= self.push_thresh:
                    self.rx.append(self.isr & ((1 << self.push_thresh) - 1)
                                   if not self.in_shift_right else self.isr)
                    self.isr, self.isr_count = 0, 0
        elif opc == 0b011:                      # OUT
            dest, n = (rest >> 5) & 7, (word & 0x1F) or 32
            if self.autopull and self.osr_count >= self.pull_thresh:
                if self.tx:
                    self.osr, self.osr_count = self.tx.pop(0), 0
                else:
                    stalled = True
            if not stalled:
                val = self._out_shift(n)
                if dest == 0:
                    self.set_pins(self.out_base, n, val)
                elif dest == 1:
                    self.x = val
                elif dest == 2:
                    self.y = val
                elif dest == 4:
                    self.set_pins(self.out_base, n, val, dirs=True)
                else:
                    raise NotImplementedError(f"OUT dest {dest}")
        elif opc == 0b100:                      # PUSH/PULL
            if (rest >> 7) & 1:                 # PULL
                if self.tx:
                    self.osr, self.osr_count = self.tx.pop(0), 0
                else:
                    stalled = True              # block assumed
            else:                               # PUSH
                if len(self.rx) < 4:
                    self.rx.append(self.isr)
                    self.isr, self.isr_count = 0, 0
                else:
                    stalled = True
        elif opc == 0b101:                      # MOV
            dest, op_, src = (rest >> 5) & 7, (rest >> 3) & 3, word & 7
            srcval = {1: self.x, 2: self.y, 3: 0,
                      6: self.isr, 7: self.osr}.get(src)
            if srcval is None:
                raise NotImplementedError(f"MOV src {src}")
            if op_ == 1:
                srcval = (~srcval) & 0xFFFFFFFF
            if dest == 1:
                self.x = srcval
            elif dest == 2:
                self.y = srcval
            elif dest == 6:
                self.isr, self.isr_count = srcval, 0
            elif dest == 7:
                self.osr, self.osr_count = srcval, 0
            else:
                raise NotImplementedError(f"MOV dest {dest}")
        else:
            raise NotImplementedError(f"opcode {opc:#05b}")

        self.bus.commit(t)
        if stalled:
            return                              # retry same instr next cycle
        if advance:
            self.pc = (self.pc + 1) % len(self.words)
        elif self.pc >= len(self.words):        # jmp past end wraps
            self.pc = 0
        self.delay_left = delay


# ========================================================================
# Mock WD33C93A: register file + datasheet enforcement at the pins
# ========================================================================
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

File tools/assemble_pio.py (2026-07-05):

#!/usr/bin/env python3
"""Stage-2 PIO verification: really assemble the ARCHITECTURE.md programs.

check_pio_timing.py (stage 1) validates encoding-field budgets and
simulates strobe timing, but it parses the source text itself — it can't
catch a syntax error, a mis-assembled instruction, or a wrong side-set
declaration. This tool closes that gap by running the real `pioasm` on
the exact code blocks in ARCHITECTURE.md and inspecting its output:

  1. Extracts every ```pioasm block (same regex as check_pio_timing.py).
  2. Minimal defensive cleaning only: strips `;` comments from directive
     lines that some pioasm versions reject them on (currently a no-op —
     pioasm 2.2.0 accepts the blocks verbatim). The doc itself is never
     modified.
  3. Compiles each .program standalone; on failure reports pioasm's
     error (which includes line/column) and exits non-zero.
  4. Parses the generated C header: instruction array, wrap target/top,
     and the sm_config_set_sideset(...) call.
  5. Asserts side-set config == (3, false, false): 3 bits, mandatory
     (non-opt), maps to pins (not pindirs).
  6. Reports the 32-slot instruction budget across all programs.
  7. Verifies the `mov osr, ~null` idiom assembles to the correct
     encoding: bits 15:13=101 (MOV), dest 7:5=111 (OSR), op 4:3=01
     (invert), src 2:0=011 (NULL) -> 0xA0EB with a zeroed delay/side
     field. Checked both in-program (masking the side/delay field) and
     via a standalone compile.

Run from the repo root:
    python3 tools/assemble_pio.py
Exit 0 = everything compiled and matched; non-zero otherwise.
"""

import os
import re
import subprocess
import sys
import tempfile

DOC = "ARCHITECTURE.md"

PIOASM_CANDIDATES = [
    "/home/harri/pico/EBD_IPKVM/build/pioasm-install/pioasm/pioasm",
    "pioasm",  # PATH
]
PIOASM_SDK_SRC = "/home/harri/pico/pico-sdk/tools/pioasm"

EXPECT_SIDESET = ("3", "false", "false")   # bits, optional, pindirs
PIO_SLOTS = 32

# mov osr, ~null with delay/side-set field zeroed:
#   15:13 opcode MOV=101 | 12:8 delay/side | 7:5 dest OSR=111
#   | 4:3 op invert=01 | 2:0 src NULL=011
MOV_OSR_INV_NULL = 0xA0EB
FIELD_MASK = 0xE0FF                        # everything except bits 12:8


def find_pioasm():
    for cand in PIOASM_CANDIDATES:
        try:
            subprocess.run([cand, "--version"], capture_output=True, check=True)
            return cand
        except (OSError, subprocess.CalledProcessError):
            continue
    # Fall back: build from SDK source
    if os.path.isdir(PIOASM_SDK_SRC):
        build = tempfile.mkdtemp(prefix="pioasm-build-")
        print(f"pioasm not found; building from {PIOASM_SDK_SRC} ...")
        subprocess.run(["cmake", PIOASM_SDK_SRC], cwd=build, check=True,
                       capture_output=True)
        subprocess.run(["make", "-j4"], cwd=build, check=True,
                       capture_output=True)
        exe = os.path.join(build, "pioasm")
        subprocess.run([exe, "--version"], capture_output=True, check=True)
        return exe
    sys.exit("FATAL: no pioasm binary found and SDK source unavailable")


def extract_programs(doc_text):
    """-> list of (name, source). Same block regex as check_pio_timing.py."""
    programs = []
    for block in re.findall(r"```pioasm\n(.*?)```", doc_text, re.S):
        name = re.search(r"\.program (\S+)", block).group(1)
        cleaned = []
        for line in block.splitlines():
            # Defensive: some pioasm versions reject ; comments on
            # directive lines. Strip them there only; leave instruction
            # comments alone (pioasm handles those, and stripping more
            # would hide doc problems this tool exists to find).
            if line.lstrip().startswith(".program"):
                line = line.split(";")[0].rstrip()
            cleaned.append(line)
        programs.append((name, "\n".join(cleaned) + "\n"))
    return programs


def compile_program(pioasm, name, source, workdir):
    src = os.path.join(workdir, f"{name}.pio")
    hdr = os.path.join(workdir, f"{name}.pio.h")
    with open(src, "w") as f:
        f.write(source)
    r = subprocess.run([pioasm, "-o", "c-sdk", src, hdr],
                       capture_output=True, text=True)
    if r.returncode != 0:
        return None, (r.stderr or r.stdout).strip()
    return open(hdr).read(), None


def parse_header(name, header):
    instrs = [int(h, 16) for h in re.findall(
        r"0x([0-9a-fA-F]{4}), //", header)]
    wrap_target = int(re.search(
        rf"#define {name}_wrap_target (\d+)", header).group(1))
    wrap = int(re.search(rf"#define {name}_wrap (\d+)", header).group(1))
    ss = re.search(
        r"sm_config_set_sideset\(&c, (\d+), (\w+), (\w+)\)", header)
    sideset = ss.groups() if ss else None
    length = int(re.search(r"\.length = (\d+),", header).group(1))
    ver_m = re.search(rf"#define {name}_pio_version (\d+)", header)
    pio_version = int(ver_m.group(1)) if ver_m else 0
    return instrs, length, wrap_target, wrap, sideset, pio_version


def check_mov_osr_inv_null(pioasm, workdir):
    """Standalone compile of the idiom, then decode the fields."""
    hdr, err = compile_program(
        pioasm, "movtest", ".program movtest\n    mov osr, ~null\n", workdir)
    if err:
        return f"standalone compile failed: {err}"
    instr = parse_header("movtest", hdr)[0][0]
    checks = [
        ("opcode MOV (101)",   (instr >> 13) & 0x7, 0b101),
        ("dest OSR (111)",     (instr >> 5) & 0x7,  0b111),
        ("op invert (01)",     (instr >> 3) & 0x3,  0b01),
        ("src NULL (011)",     instr & 0x7,         0b011),
    ]
    bad = [f"{what}: got {got:#b}, want {want:#b}"
           for what, got, want in checks if got != want]
    if bad:
        return "; ".join(bad)
    if instr != MOV_OSR_INV_NULL:
        return f"encoded {instr:#06x}, expected {MOV_OSR_INV_NULL:#06x}"
    return None
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

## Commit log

2026-02-28 Initial commit: KiCad SCSI hardware project
    [scsi.kicad_pcb, scsi.kicad_sch]
2026-02-28 Ignore KiCad lock files
2026-02-28 Fancied up board graphics
    [scsi.kicad_pcb]
2026-02-28 Fixed mounting holes
    [scsi.kicad_pcb]
2026-02-28 Fixed mounting holes - 2
    [scsi.kicad_pcb]
2026-03-02 Final Board Design as of First Manufacture - V1.0
    [scsi.kicad_pcb]
2026-07-05 Full 33C93A programming reference, verification tools, and datasheets
    Adds complete software architecture for Pico <-> AM33C93A SCSI interface
    covering initiator and target modes, PIO/DMA transport, full register,
    interrupt, and command reference with silicon variant flags.
    ARCHITECTURE.md: 1184-line reference, all timing tables and interrupt
    code tables verified visually against PDF page images.
    Tools:
    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
2026-07-05 Add board render image to README
2026-07-05 Add pio_sim.py: behavioral PIO simulator with mock 33C93A register file
    Stage-3 verification tool: cycle-accurate PIO execution against a mock
    33C93A chip model. 9 tests verifying indirect addressing protocol,
    INTRQ semantics, 7us LCI rule, DRQ/DACK burst mode, and FIFO-stall
    hazard detection. All pass.
    Adds the session log to session/ with showThinkingSummaries enabled —
    23 cleartext thinking blocks, 20,684 chars of reasoning captured.
    [pio_sim.py]
2026-07-06 Update session log and tools with B-variant pipelined burst support
    Session log (788b35c3): grew from 658K to 846K with B-variant reasoning.
    36 thinking blocks, all cleartext, 11 mentioning pipeline/B-variant logic.
    pio_sim.py: added chip_variant parameter, BURST_SPEC table, stateful
    pipelined read model tracking DACK-down and per-byte RE-up edges.
    10 tests pass including golden-burst-pipeline and variant-probe.
    tools/README.md: documents variant parameter, both timing models, and
    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

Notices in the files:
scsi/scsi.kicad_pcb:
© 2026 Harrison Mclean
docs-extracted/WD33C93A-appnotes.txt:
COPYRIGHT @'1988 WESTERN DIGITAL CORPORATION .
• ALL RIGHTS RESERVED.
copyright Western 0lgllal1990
